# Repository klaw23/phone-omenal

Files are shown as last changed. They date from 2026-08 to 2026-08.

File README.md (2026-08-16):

# Phone-omenal 📞

**An open source telephone.** A box with an analog phone jack: plug in any
phone — a 1962 rotary, a Mickey Mouse phone, whatever the thrift store had —
and it calls other phones on your network through an open switchboard server
you (or anyone) can run. Everything is open: enclosure, electronics, firmware,
server.

The commercial inspiration is the Tin Can kids' landline; this is the
non-commercial, hackable, federated cousin.

## The build: ESP32 + a SLIC module + any old phone

**Start with [docs/esp32-build-guide.md](docs/esp32-build-guide.md).** It's the
whole project: complete parts and tools shopping list (~$120 all-in, no
soldering), a hardware crash course written for software engineers, and six
milestones — each one ends with something you can see or hear:

1. **Milestone 0** — stand up the Asterisk switchboard in Docker, call between
   two softphones (do this before any parts arrive)
2. **Hello world** — ESP-IDF toolchain, first flash
3. **Hook detection** — lift the handset, watch the serial log react
4. **Ring** — a real bell hammers because your for-loop said so
5. **Dial tone** — 350Hz + 440Hz through a real earpiece
6. **Digits** — decode rotary pulses (and touch-tones)
7. **The call** — dial 600 on a rotary phone, hear yourself echo back via SIP

## Repo layout

| Path | What |
|---|---|
| `docs/` | **The build guide — start here** · plus the provisioning & switchboard spec |
| `server/` | Asterisk switchboard + management web app: `docker compose up -d` and go |
| `firmware/` | Milestone example code matching the guide |
| `hardware/enclosure/` | Model 01 printed enclosure (OpenSCAD + STLs + 3D viewer) — fits the guide's electronics once they graduate from breadboard to perfboard |
| `future/` | Future work, tucked away: the Model 02 custom PCB and its smaller enclosure. Ignore until the breadboard build is making calls |

## Licenses

- Firmware & server configs: **MIT**
- Hardware (enclosure, PCB): **CERN-OHL-S v2**
- Documentation: **CC BY-SA 4.0**

## Standing on shoulders

[RetroPhone](https://github.com/ktownsend-personal/RetroPhone) proved the
ESP32+SLIC phone interface; [ESP32-SIP-Voice](https://github.com/GeorgeBregman/ESP32-SIP-Voice)
provides the SIP stack; [Asterisk](https://www.asterisk.org/) is the switch;
[PhreakNet](https://phreaknet.org/) and [NPSTN](https://npstn.us) showed hobbyist
phone networks are a thriving genre.

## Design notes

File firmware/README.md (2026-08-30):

# Firmware

Milestone example code referenced by the build guide
(`docs/esp32-build-guide.md`). Each file is the core of one milestone, written
for ESP-IDF v6.0.2 on the ESP32-A1S Audio Kit. They're deliberately small —
paste into an `idf.py create-project` skeleton as you reach each milestone,
rather than cloning something monolithic you didn't write yet.

| File | Milestone |
|---|---|
| `examples/01_hook.c` | Hook detection with debounce |
| `examples/02_ring.c` | Ring cadence generator |
| `examples/03_dialtone.c` | Dial/busy/ringback tone synthesis |
| `examples/04_digits.c` | Rotary pulse counting + MT8870 DTMF |
| `examples/05_provision.c` | WiFi with captive-portal fallback + LAN config page (spec §1) |
| `examples/06_ble_config.c` | Always-on BLE config GATT service (companion to 05) |
| `ble-config.html` | Web Bluetooth page that talks to 06 — open from disk in Chrome/Edge |

Milestone 5 (the actual SIP call) builds on
[ESP32-SIP-Voice](https://github.com/GeorgeBregman/ESP32-SIP-Voice) (MIT) —
the guide describes the grafting points. Once that integration exists as real
code, it lives here as `phone-omenal-fw/`.

GPIO assignments live at the top of each file; the guide's "AudioKit pin
caveat" explains why you might need to change them for your board revision.

`05_provision.c` and `06_ble_config.c` implement
`docs/provisioning-and-switchboard-spec.md`: captive portal only when WiFi is
failing, config page on the LAN IP (`http://phone-omenal.local`) once joined,
BLE reachable always, everything PIN-gated. Unlike 01–04 they are reference
code for a real subsystem rather than a bench exercise — wire them into the
Milestone 5 project alongside the SIP stack.

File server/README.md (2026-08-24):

# Switchboard server

Two pieces:

- **Asterisk** — the actual phone switch. Dialplan routes any 3–6 digit
  number starting 1–9, plus the service range (600 echo test, 601 playback).
  Endpoint definitions live in `asterisk/pjsip_devices.conf`.
- **Switchboard app** (`switchboard/`) — accounts, devices, and numbers, per
  the spec (`docs/provisioning-and-switchboard-spec.md`). Admins create users
  and approve number requests; users add devices and read their call logs; the
  boxes log in via its API to show status and the admin's contact email. It
  renders `pjsip_devices.conf` from its database and reloads Asterisk over AMI.

The app is optional for Milestone 0: `pjsip_devices.conf` ships with starter
extensions 101–103 so softphone testing works immediately.

## Docker (laptop/VPS/64-bit Pi)

On **Linux** (including a 64-bit Pi), host networking keeps SIP/RTP simple:

```bash
docker compose up -d
# web UI:
open http://localhost:8080     # log in: admin / changeme-admin (CHANGE IT)
# verify registrations:
docker exec -it phone-omenal-switchboard asterisk -rx "pjsip show contacts"
# watch RTP while debugging audio:
docker exec -it phone-omenal-switchboard asterisk -rx "rtp set debug on"
```

On **macOS/Windows** there is no host networking — Docker Desktop's "host" is
its Linux VM, so the containers come up healthy but `localhost:8080` refuses
the connection. Add the override, which publishes real ports and joins the app
to Asterisk's network namespace (so AMI stays on loopback, as on the Pi):

```bash
docker compose -f docker-compose.yml -f docker-compose.mac.yml up -d --build
```

It publishes 8080/tcp, 5060/udp, and the RTP range in `asterisk/rtp.conf`
(10000-10030 — deliberately narrow; every published UDP port costs a userland
proxy on Docker Desktop).

Before exposing anything beyond your LAN: set `ADMIN_PASSWORD`,
`SWITCHBOARD_SECRET`, and the AMI secret (`asterisk/manager.conf` +
`AMI_PASS` in `docker-compose.yml`) — the defaults are placeholders.

## Native install (better for 32-bit Pis like the Pi 2)

```bash
sudo apt update && sudo apt install asterisk python3-flask
sudo cp asterisk/*.conf /etc/asterisk/
sudo systemctl restart asterisk
sudo asterisk -rx "pjsip show endpoints"

# switchboard app (writes /etc/asterisk/pjsip_devices.conf, so run as a user
# that can — or point ASTERISK_CONF_DIR somewhere asterisk includes):
cd switchboard
ASTERISK_CONF_DIR=/etc/asterisk python3 app.py
```

## How number assignment flows

1. Admin creates a user (admin panel → Users).
2. User logs in, adds a device — a SIP password is generated.
3. User requests a number (a specific free one, or "next available").
4. Admin approves → the app writes the endpoint into `pjsip_devices.conf`,
   reloads Asterisk, and the user's device page shows the SIP credentials to
   type into the box's config page.

Numbers are 3–6 digits, never starting with 0 (`0…` is reserved for future
switchboard-to-switchboard dialing) and never in `6XX` (service range).

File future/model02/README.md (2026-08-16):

# Future work: Model 02 — the custom PCB

**Not the current project.** The current project is the ESP32 breadboard build
in `docs/esp32-build-guide.md`. This directory is a head start on what comes
*after* that works: collapsing the Audio Kit + perfboard + modules into a single
custom 80×54mm board, in a box half the size.

What's here, for when that day comes:

- `pcb/model02.kicad_pcb` — routed KiCad board (machine-routed rev A,
  DRC-clean electrically, **not yet reviewed by human eyes** — read
  `pcb/model02_board_design.md` §8 before spending money)
- `pcb/gerbers/` + `pcb/model02_bom.csv` + `pcb/model02_cpl_top.csv` — the
  JLCPCB upload set
- `pcb/model02_board_design.md` — the full engineering design doc
- `pcb/generator/` — the Python scripts that generate and route the board
- `model02.scad` / STLs / viewer — the matching smaller enclosure (91×65×28mm)

The right time to open this folder: the breadboard build makes calls reliably,
the firmware has settled, and you want ten of these instead of one.

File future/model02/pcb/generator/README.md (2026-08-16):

# Board generator

The Model 02 PCB is *generated*, not hand-drawn: `gen_board.py` places every
footprint and builds the full netlist with KiCad's pcbnew Python API, the
freerouting autorouter routes it (via Specctra DSN/SES: `import_ses.py`), and
`finish_board.py` stitches ground islands and runs DRC. To reproduce or modify:
edit the PARTS/NETS tables in gen_board.py and re-run the pipeline — the
design doc (../model02_board_design.md) explains every connection.

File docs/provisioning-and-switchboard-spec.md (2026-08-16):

# Phone-omenal — provisioning & switchboard spec

How a box gets configured, and how the switchboard manages people, devices,
and numbers. Firmware reference code: `firmware/examples/05_provision.c` and
`06_ble_config.c`. Server implementation: `server/switchboard/`.

## 1. Box configuration

The box stores five settings (in NVS flash): WiFi SSID, WiFi password,
switchboard address, SIP username (= its phone number), SIP password.
Plus a 4–8 digit **device PIN** (printed on a sticker inside the lid) that
gates every config surface.

Three ways in, one rule each:

| Surface | Available when | Why |
|---|---|---|
| **Captive portal** (box's own AP) | WiFi is failing: no stored credentials, or ~45s / 5 straight failed joins | First-time setup and "I typed the wrong password" recovery |
| **LAN config page** (`http://phone-omenal.local`) | Box is on WiFi | Everyday reconfiguration; the switchboard portal deep-links here per device |
| **BLE web config** (Web Bluetooth GATT) | Always advertising | Universal escape hatch — works even when WiFi is wedged. Chrome/Edge/Android only (no iOS Web Bluetooth); the portal covers everyone else |

The BLE page (`firmware/ble-config.html`) is pure client-side — the browser
talks GATT directly to the box, so no server hosts it. Web Bluetooth requires
a secure context (`https://`, `localhost`, or `file://`), which is why it is
NOT served by the plain-HTTP switchboard: open it from disk, or host it on
any HTTPS static host.

State machine:

```
            boot
             │
      creds stored? ──no──► AP MODE: SSID "Phone-omenal-XXXX",
             │yes           captive DNS, portal at 192.168.4.1
             ▼                  │ creds submitted
        JOIN WiFi ◄─────────────┘
        │        │
     joined    5 fails / 45s
        │        └──────────► AP MODE (portal shows last failure reason;
        ▼                     keeps retrying STA in the background — APSTA)
   CONNECTED: LAN page up, mDNS "phone-omenal",
   SIP registers, AP torn down
                                     BLE: advertising in every state
```

Rules:

- **Portal never coexists with calls** by construction: no WiFi → no SIP.
- The portal must display the last join failure ("wrong password for
  `MyWifi`", "no IP from DHCP") or users retry the same typo forever.
- **Auth**: every surface requires the device PIN before reading or writing
  anything. BLE additionally uses LE pairing. The LAN page is plain HTTP
  (TLS with a self-signed cert on an ESP32 only trains users to click through
  scare screens), so: LAN-only, PIN required, and **stored secrets are never
  echoed back** — the page shows `SSID: MyWifi ✓` and password fields stay
  blank.
- **Coexistence**: BLE advertises always, but GATT writes are deferred while
  a call is up (one 2.4GHz radio, time-sliced). Firmware uses NimBLE, not
  Bluedroid — RAM.
- After the box registers, it logs into the switchboard API with its SIP
  credentials and displays the **switchboard admin's email** on all three
  config surfaces ("problems? contact …").

## 2. Numbering plan

- A number is a dialable extension: digits only, 3–6 digits.
- **First digit is never 0.** The entire `0…` space is reserved as the
  inter-switchboard prefix for future federation (dial `0` + switchboard +
  number). The dialplan hard-reserves `_0.` so nothing can ever squat on it.
- **`6XX` is the service range** (600 echo test, 601 playback, future
  voicemail etc.) — not assignable to devices.
- Everything else (`100`–`599`, `700`–`999`, and longer) is assignable.
- One number ↔ one device. The number **is** the device's SIP username; a
  device without a number can't register (there'd be nothing to reach it at).

## 3. Switchboard roles

**Admin** (bootstrap account, has an email address — the one shown on boxes):

- create/disable user accounts
- create devices for any user, assign/change/release numbers directly
- approve or reject number requests
- see every device, registration status, and call log

**User** (created by an admin):

- add devices (each gets a generated SIP password, shown once)
- request a number for a device — a specific free one or "next available";
  assignment happens when an admin approves
- see their devices: number, registration status (from Asterisk), SIP
  credentials, and per-device call logs (from CDR)

## 4. Server architecture

```
Flask app (server/switchboard, SQLite) ──writes──► asterisk/pjsip_devices.conf
        │                                            (endpoint per number)
        ├──AMI :5038──► Asterisk  ("pjsip reload", "pjsip show contacts")
        └──reads──── /var/log/asterisk/cdr-csv/Master.csv  (call logs)
```

- The app owns `pjsip_devices.conf` (one `[number]` endpoint per assigned
  device, rendered from the DB) and reloads Asterisk over AMI after every
  change. `pjsip.conf` keeps the transport + templates and `#include`s it.
  The static dialplan needs no regeneration: `_[1-9]XX` (and longer
  patterns) already route any legal number.
- Registration status comes from parsing `pjsip show contacts` over AMI;
  call logs from the CDR CSV, filtered to rows where the device's number is
  caller or callee.
- Pi 2 friendly: Flask + SQLite + raw-socket AMI, no other dependencies.

## 5. HTTP API (used by the box and the BLE/portal pages)

| Endpoint | Auth | Returns |
|---|---|---|
| `POST /api/login` `{username, password}` | SIP creds (number + password) | `{token, number, owner, admin_email}` |
| `GET /api/me` | `Authorization: Bearer <token>` | same, minus token — the box polls this to show status + admin email |

Tokens are HMAC-signed, 24h expiry, no server-side session state.

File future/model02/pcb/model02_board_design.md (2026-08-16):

# Phone-omenal — Model 02 board design package

A single custom PCB that replaces the ESP32 Audio Kit + perfboard + breakout modules
from the Model 01 prototype. Design goal: **compactness** — one board, one USB-C cable,
one RJ11 jack, in a box barely bigger than a credit card footprint.

This document is everything except the CAD capture itself: exact parts, exact
connections, the floorplan, and the fab strategy. Capturing it in KiCad from these
tables is mechanical work (a focused weekend); every connection is specified below.
Board outline with hole and connector positions is provided as `model02_outline.dxf`
for direct import into KiCad's Edge.Cuts layer.

---

## 1. Architecture

```
                 ┌──────────────────────────────────────────────┐
  USB-C 5V ──►──┤ protection ─► 5V rail ────────► KS0835F SLIC ─┼──► RJ11 ──► phone
                 │     │                            ▲  ▲  │      │
                 │     └─► SY8089 buck ─► 3.3V      │  │  │audio │
                 │                          │       │  │  ▼      │
  USB-C D+/D- ──┼─► ESP32-S3-WROOM-1 ◄──────┘       │  │ ES8388  │
                 │      │     │  (native USB)       │  │ codec   │
                 │      │     └── GPIO: RM,F/R,PD ──┘  │  ▲      │
                 │      │         GPIO: SHK ◄──────────┘  │      │
                 │      ├── I2S + I2C ────────────────────┘      │
                 │      └── GPIO ◄── HT9170D DTMF ◄── audio tap  │
                 └──────────────────────────────────────────────┘
```

WiFi + SIP + G.711 run on the ESP32-S3. The ES8388 codec is the board's "sound card."
The KS0835F SLIC (still the proven off-the-shelf module, mounted flat on a right-angle
header) makes the analog phone line. The HT9170D decodes touch-tones in hardware —
the RetroPhone project's hard-won lesson is that software DTMF is unreliable, and this
chip is under a dollar. Rotary pulse dialing needs no hardware at all (counted on SHK).

Why the SLIC stays a module in rev A: a from-scratch SLIC (e.g. Si3210 ProSLIC) is a
serious analog/BOM undertaking with its own transformer-less ringing circuits. The
module is $8, proven in this exact role, and hand-solders in one minute. Integrating
a real SLIC chip is the natural Model 03 once the network exists.

## 2. Bill of materials

SMT parts are JLCPCB-assembly-friendly jellybeans; check live stock at order time
(all have drop-in equivalents). THT/manual parts marked ✋.

| Ref | Part (MPN) | Package | Role | ~$ |
|---|---|---|---|---|
| U1 | ESP32-S3-WROOM-1-N8R2 | module | MCU, WiFi, native USB | 3.50 |
| U2 | ES8388 | QFN-28 | stereo audio codec | 1.50 |
| U3 | HT9170D | SOIC-18 | DTMF receiver (MT8870-compatible) | 0.60 |
| U4 | SY8089A1AAC | SOT23-5 | 5V→3.3V buck, 2A | 0.30 |
| U5 | USBLC6-2SC6 | SOT23-6 | USB ESD protection | 0.25 |
| U6 | LM358 (DNP) | SOIC-8 | audio buffer stuffing option | 0.20 |
| M1 ✋ | KS0835F SLIC module | 11-pin SIL | FXS line interface | 8.00 |
| J1 ✋ | RJ11 6P4C jack, right-angle THT | — | phone line | 0.60 |
| J2 | USB-C receptacle 16-pin (e.g. TYPE-C-31-M-12) | SMT+shell | power + programming | 0.40 |
| J3 ✋ | 11-pin right-angle female header, 2.54mm | THT | SLIC mounts flat into this | 0.30 |
| X1 | 3.579545 MHz crystal | HC-49/SMD | HT9170D colorburst clock | 0.30 |
| Y1 | WS2812B-2020 | 2020 | status LED (front light pipe) | 0.15 |
| F1 | polyfuse 1A (MF-MSMF100) | 1812 | VBUS protection | 0.10 |
| D1 | SMBJ100CA bidirectional TVS | SMB | TIP/RING surge clamp (above ring voltage!) | 0.25 |
| L1 | 2.2µH, ≥2A | 0806/1212 | buck inductor | 0.10 |
| SW1, SW2 | tactile switch | SMT | EN, BOOT | 0.20 |
| — | R/C 0603 kit per section 4 | 0603 | ~30 passives | 1.00 |

Board: 2-layer, 1.6mm FR-4, HASL, **80 × 54 mm**, corners chamfered 6mm.
Five boards SMT-assembled at JLCPCB: roughly $60–90 + the five SLIC modules.
Solder M1/J1/J3 yourself (three parts, ten minutes).

## 3. ESP32-S3 pin map

| GPIO | Net | Dir | Notes |
|---|---|---|---|
| 19, 20 | USB D−, D+ | — | native USB (fixed pins), via U5 ESD |
| 1 / 2 | I2C SDA / SCL | I/O | ES8388 control (addr 0x10), 4.7k pullups |
| 4 | I2S MCLK | out | S3 routes MCLK on any pin via GPIO matrix |
| 5 / 6 | I2S BCLK / LRCLK | out | |
| 7 | I2S DOUT → codec DIN | out | ESP32 → phone audio |
| 8 | I2S DIN ← codec DOUT | in | phone → ESP32 audio |
| 10 | SLIC SHK | in | hook status + pulse dialing, **via divider** (§4.3) |
| 11 | SLIC RM | out | ring mode enable |
| 12 | SLIC F/R | out | toggle at 20 Hz while RM high = ring |
| 13 | SLIC PD | out | SLIC power-down |
| 14, 15, 17, 18 | HT9170 Q1–Q4 | in | decoded DTMF digit |
| 21 | HT9170 DV | in | data-valid, use as interrupt |
| 38 | WS2812 DIN | out | status LED |
| 0 | BOOT switch | in | strapping pin, rear pinhole access |

Strapping pins 3, 45, 46 left unconnected/default. All chosen GPIOs avoid
flash/PSRAM-reserved pins on the WROOM-1 module.

## 4. Subsystem circuits

### 4.1 Power
- USB-C VBUS → F1 polyfuse → **5V rail** (powers SLIC directly — ring generation
  is strongest at 5V). CC1/CC2 each pulled to GND with 5.1k (advertises 5V/up-to-3A sink).
- 5V → U4 SY8089 buck (L1 1µH, 22µF in, 2×22µF out) → **3.3V rail** for ESP32-S3,
  ES8388, HT9170D. WiFi TX bursts hit ~500mA; the 2A buck loafs. (Pad-compatible
  AMS1117 fallback footprint optional but the buck runs cool and is the same price.)
- Bulk: 100µF electrolytic or 2×22µF ceramic on the 5V rail near the SLIC — ring
  bursts draw current spikes.

### 4.2 Audio path (the part that earns the board its keep)
ES8388 is stereo; the phone line is mono — use LOUT1/RIN1, leaving a spare channel.

- **To the phone:** ES8388 LOUT1 → 100Ω series → 4.7µF film/X7R coupling cap →
  SLIC **VR** (audio input). Provision R-divider pads (DNP 0Ω/open by default) to
  trim level in rev A bring-up.
- **From the phone:** SLIC **VX** → 4.7µF coupling → 10k series → ES8388 **RIN1**
  (line input, not mic input — VX is line level). PGA in the codec handles fine trim.
- **DTMF tap:** VX also feeds HT9170D via the datasheet single-ended network:
  0.1µF into IN−, 100k input R, 100k feedback R IN−→GC, IN+ to VREF. X1 crystal
  + 2×18pF across OSC1/OSC2.
- **Stuffing option:** U6 LM358 buffer footprints sit in both audio legs, bypassed
  by 0Ω links by default. If levels or impedances disappoint during bring-up
  (RetroPhone needed an op-amp here), populate U6 and its gain network instead of
  respinning. This is the cheapest insurance on the board.
- **Ring-bleed filter:** RetroPhone reports the 20Hz ring bleeding into audio.
  Provision a simple RC high-pass (DNP) at RIN1 (e.g. 300Hz corner: 10k + 47nF) —
  telephone audio is 300–3400Hz anyway, and firmware mutes the codec during ring
  cadence as the first line of defense.

### 4.3 SLIC interface (M1 on J3, lying flat)
KS0835F pinout: 1-2 RING/TIP, 3 F/R, 4 RM, 5 SHK, 6 VR, 7 VX, 8 NC, 9 GND,
10 +5V, 11 PD.

- Supply pin 10 from the 5V rail with 100µF nearby.
- **SHK is 5V logic → divider 10k/15k to GPIO10** (3.0V high). RM/F/R/PD are
  driven at 3.3V, which clears TTL V_IH at 5V supply — direct connection.
- TIP/RING → J1 RJ11 center pair, with D1 (SMBJ100CA) across the pair. The TVS
  must stand off the ~±60–90V ring pulses, hence 100V. This is a desk device with
  a 2m handset cord, not a building wiring run — heavier telecom protection
  (TISP surge protectors, line fuses) is a Model 03 concern.
- Keep-out: route TIP/RING and the SLIC's line side away from codec inputs;
  20 mil clearance minimum on the ring-voltage nets.

### 4.4 Misc
- EN: 10k pullup + 1µF to GND + SW1 to GND. BOOT: SW2 on GPIO0, reachable through
  a 2mm pinhole in the rear wall (firmware updates are OTA after first flash;
  the pinhole is the break-glass path).
- WS2812B-2020 at the front edge behind a 3mm light pipe: registration status,
  ring flash, "line claimed" colors — the box's only face.

## 5. Floorplan (80 × 54, origin front-left, dims in mm)

```
 rear  ┌──────────────────────────────────────────────┐
       │ [ESP32-S3 ▓antenna→edge]   [USB-C @ x=40]  ○ │   ○ = M2.5 holes at
       │   x=7..25, keep-out under    [BOOT pinhole]  │   (10,10)(70,10)
       │   antenna: no copper       [buck U4 + L1]    │   (10,44)(70,44)
       │                                              │
       │        [KS0835F lying flat on J3]            │   corners chamfered 6mm
       │         50 × 20 zone, x≈20..71               │   (clears the enclosure's
       │                                              │    corner screw posts)
       │ [ES8388+passives]     [HT9170D + X1]         │
       │                                              │
       │  [RJ11 J1 @ x=25]   [LED Y1 @ x=60]          │
 front └──────────────────────────────────────────────┘
```

- ESP32-S3 antenna overhangs/abuts the rear edge with full copper keep-out beneath.
- Buck loop (U4-L1-caps) tight, far corner from the codec; WS2812 data line routed
  away from audio nets.
- J1 and J2 protrude through the enclosure walls; Y1 sits 1mm behind the front wall
  light-pipe hole.
- Ground pour both layers, stitched; single reference, star only the SLIC's
  noisy 5V leg.

## 6. Fab & assembly plan

1. JLCPCB 2-layer, HASL, any color (it lives in a box). Economic SMT assembly,
   top side only — every SMT part above is from their parts-library ecosystem;
   substitute equivalents for anything out of stock at order time.
2. Hand-solder J1, J3 (and the USB-C shell tabs if you chose the THT-shell variant).
3. Push M1 (SLIC module) into J3. It lies flat over the board, max height ~13mm.
4. First power-up **without** M1: verify 5V, 3.3V, USB enumeration, flash firmware.
5. Insert M1, run bring-up in the same ladder as the breadboard: SHK detect →
   ring test → dial tone → DTMF/pulse digits → SIP call.

Order 5 boards and expect to want a rev B — that is normal and cheap (~$2/bare
board on re-order). Rev A's DNP stuffing options (LM358 path, dividers, RC filter)
exist precisely so most surprises are jumper changes, not respins.

## 7. What the compactness buys

| | Model 01 (modules) | Model 02 (custom board) |
|---|---|---|
| Boards inside | AudioKit + perfboard + 3 modules | one |
| Tallest part | SLIC standing, 20.3mm | SLIC flat, ~13mm |
| Enclosure | 145 × 101 × 39 mm | **91 × 65 × 28 mm** (≈½ the volume) |
| Cables inside | 15+ jumpers | zero |
| Cost @ qty 5 | ~$35/unit in modules | ~$25/unit assembled + module |
| Programming | USB-UART on AudioKit | native USB-C, OTA after first flash |

Enclosure files: `model02.scad`, `model02_base.stl`, `model02_lid.stl` — same
open-source enclosure language (rotary-dial vents, engraved nameplate), rebuilt
around this board's exact connector positions.

## 8. Rev A as-built (KiCad files)

The generated, routed board (`model02.kicad_pcb`) supersedes a few §2/§5 details:

- **USB-C moved to x=55** on the rear edge. The stock KiCad ESP32-S3-WROOM-1
  footprint embeds Espressif's antenna keep-out, which covers the rear-LEFT
  region — the connector now sits clear of it (better RF, too).
- **Mounting holes** ended up at (33,12), (70,10), (10,37), (70,44) after
  clearing the module, codec, and connector courtyards. The enclosure
  (`model02.scad`) and `model02_outline.dxf` are updated to match.
- ES8388 is **QFN-28** (its only package); buck uses 2.2µH with a 100k/22k
  FB divider (0.6V reference → 3.3V).
- Routing: freerouting autorouter + scripted cleanup; **DRC: 0 electrical
  violations, 0 unconnected items**. Remaining DRC entries are cosmetic
  (silkscreen label overlaps, library-sync notices).
- Honest caveat: this is a machine-routed rev A. It is electrically correct
  per the netlist and passes DRC, but no human has eyeballed the analog
  routing. Treat the first 5 boards as the bring-up batch they are.

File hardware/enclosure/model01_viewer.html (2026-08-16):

# Phone-omenal — Model 01

closedexplodedinterior

145 × 101 × 39 mm · drag to orbit, scroll to zoom · CERN-OHL-S

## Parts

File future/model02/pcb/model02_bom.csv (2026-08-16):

Designator | Value | Footprint | MPN / note
U1 | ESP32-S3-WROOM-1-N8R2 | ESP32-S3-WROOM-1 | ESP32-S3-WROOM-1-N8R2
U2 | ES8388 | QFN-28-1EP_5x5mm_P0.5mm_EP3.35x3.35mm | ES8388
U3 | HT9170D | SOIC-18W_7.5x11.6mm_P1.27mm | HT9170D
U4 | SY8089AAAC | SOT-23-5 | SY8089AAAC
U5 | USBLC6-2SC6 | SOT-23-6 | USBLC6-2SC6
J1 | RJ11-6P4C | RJ14_Connfly_DS1133-S4_Horizontal | RJ11 6P4C DS1133-S4
J2 | USB-C 16pin | USB_C_Receptacle_HRO_TYPE-C-31-M-12 | TYPE-C-31-M-12
J3 | KS0835F socket | PinSocket_1x11_P2.54mm_Horizontal | 2.54mm 1x11 R/A socket
F1 | 1A polyfuse | Fuse_1812_4532Metric | MF-MSMF100
D1 | SMBJ100CA | D_SMB | SMBJ100CA
L1 | 2.2uH | L_1210_3225Metric | generic 2.2uH
X1 | 3.579545MHz | Crystal_SMD_HC49-SD | 3.579545MHz HC49-SMD
Y1 | WS2812B-2020 | LED_WS2812B-2020_PLCC4_2.0x2.0mm | WS2812B-2020
SW1 | EN | SW_SPST_TL3342 | generic EN
SW2 | BOOT | SW_SPST_TL3342 | generic BOOT
R1 | 5.1k | R_0603_1608Metric | generic 5.1k
R2 | 5.1k | R_0603_1608Metric | generic 5.1k
R4 | 100R | R_0603_1608Metric | generic 100R
R6 | 10k | R_0603_1608Metric | generic 10k
R7 | 100k | R_0603_1608Metric | generic 100k
R8 | 100k | R_0603_1608Metric | generic 100k
R10 | 10k | R_0603_1608Metric | generic 10k
R11 | 15k | R_0603_1608Metric | generic 15k
R12 | 300k | R_0603_1608Metric | generic 300k
R13 | 330R | R_0603_1608Metric | generic 330R
R14 | 10k | R_0603_1608Metric | generic 10k
R15 | 100k | R_0603_1608Metric | generic 100k
R16 | 22k | R_0603_1608Metric | generic 22k
RP1 | 4.7k | R_0603_1608Metric | generic 4.7k
RP2 | 4.7k | R_0603_1608Metric | generic 4.7k
C1 | 22uF | C_0805_2012Metric | generic 22uF
C2 | 22uF | C_0805_2012Metric | generic 22uF
C3 | 22uF | C_0805_2012Metric | generic 22uF
C4 | 22uF | C_0805_2012Metric | generic 22uF
C5 | 4.7uF | C_0805_2012Metric | generic 4.7uF
C6 | 4.7uF | C_0805_2012Metric | generic 4.7uF
C7 | 100nF | C_0603_1608Metric | generic 100nF
C8 | 100nF | C_0603_1608Metric | generic 100nF
C9 | 1uF | C_0603_1608Metric | generic 1uF
C10 | 100uF | CP_Elec_6.3x5.8 | generic 100uF
C12 | 100nF | C_0603_1608Metric | generic 100nF
C13 | 100nF | C_0603_1608Metric | generic 100nF
C14 | 100nF | C_0603_1608Metric | generic 100nF
C15 | 100nF | C_0603_1608Metric | generic 100nF
C16 | 100nF | C_0603_1608Metric | generic 100nF
C17 | 10uF | C_0805_2012Metric | generic 10uF
C18 | 10uF | C_0805_2012Metric | generic 10uF
C19 | 100nF | C_0603_1608Metric | generic 100nF
C20 | 18pF | C_0603_1608Metric | generic 18pF
C21 | 18pF | C_0603_1608Metric | generic 18pF

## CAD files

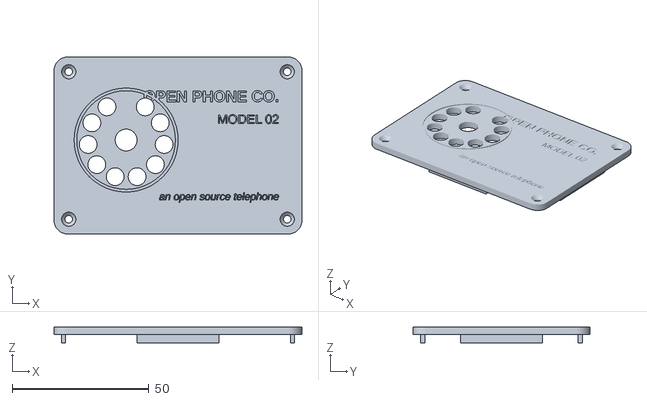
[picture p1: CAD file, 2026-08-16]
future/model02/model02_lid.stl
90.8 x 64.8 x 5.80

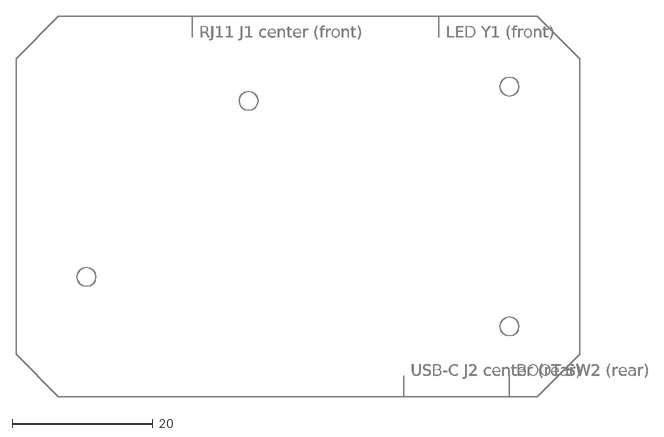
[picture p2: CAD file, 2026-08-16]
future/model02/pcb/model02_outline.dxf
RJ11 J1 center (front)
USB-C J2 center (rear)
LED Y1 (front)
BOOT SW2 (rear)

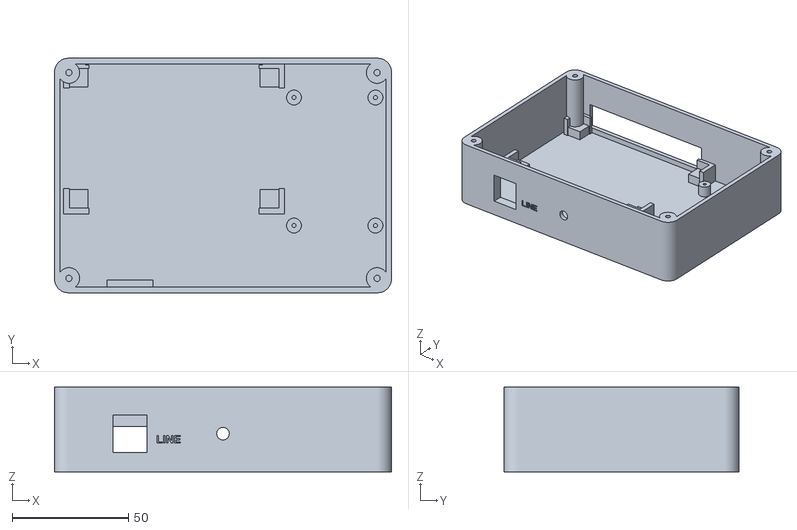
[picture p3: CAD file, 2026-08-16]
hardware/enclosure/model01_base.stl
144.8 x 100.8 x 36.4

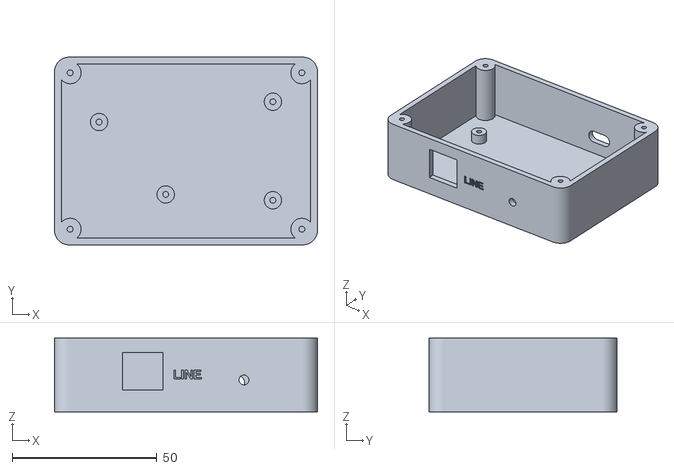
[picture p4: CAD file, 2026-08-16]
future/model02/model02_base.stl
90.8 x 64.8 x 25.4

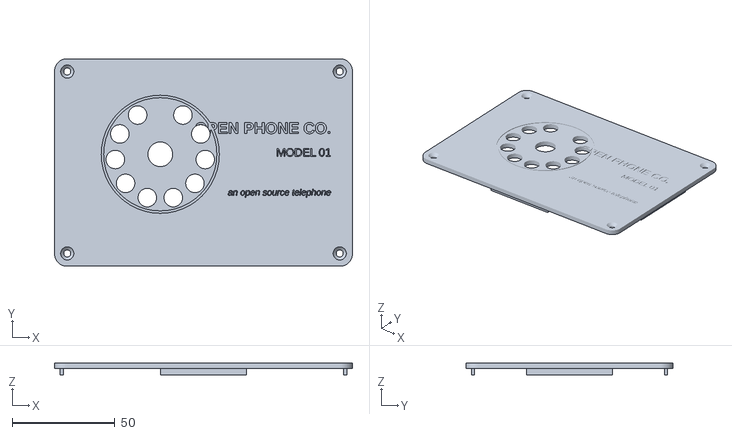
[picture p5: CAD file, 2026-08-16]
hardware/enclosure/model01_lid.stl
144.8 x 100.8 x 6.00

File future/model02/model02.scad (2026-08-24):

// ============================================================
//  PHONE-OMENAL — "Model 02" enclosure
//  Built around the custom 80x54mm PCB (see model02_board_design.md):
//  on-board RJ11, USB-C, WS2812 light pipe, SLIC module lying flat.
//  License: CERN-OHL-S / CC-BY-SA
//
//  part = "base" | "lid" | "components" | "display" | "exploded" | "interior"
// ============================================================

part = "display";

/* ---------- parameters (mm) ---------- */
wall = 2.4; floor_th = 2.4; lid_th = 2.8; corner_r = 5;

ix = 86; iy = 60; iz = 23;          // interior

// PCB: 80x54, chamfer C6, at (3,3); top of PCB sits at floor+4+1.6
pcb_x = 3;  pcb_y = 3;  pcb_w = 80; pcb_d = 54; pcb_ch = 6;
standoff_h = 4; pcb_top = floor_th + standoff_h + 1.6;
// mounting holes at board (10,10)(70,10)(10,44)(70,44) -> interior:
so_pts = [[36,15],[73,13],[13,40],[73,47]];  // matches PCB holes (33,12)(70,10)(10,37)(70,44)

// front-face features (board coords -> interior x = board x + 3)
rj_cx = 28;  rj_w = 14;  rj_z0 = floor_th+5.1; rj_z1 = floor_th+18.1; // RJ11 opening
led_cx = 63; led_d = 3.4; led_z = floor_th+8.6;                      // light pipe
// rear-face features
usb_cx = 58; usb_w = 10.5; usb_z0 = floor_th+5.1; usb_z1 = floor_th+10.1;
boot_cx = 73; boot_d = 2.2; boot_z = floor_th+7.6;                   // BOOT pinhole

// lid screws M2.5 into corner posts
post_r = 3.8; pin = 3.0; pilot = 2.05; shaft = 2.7; head = 5.2;
post_pts = [[pin,pin],[ix-pin,pin],[pin,iy-pin],[ix-pin,iy-pin]];

// rotary-dial vents
dial_cx = 24; dial_cy = 32; dial_r = 14; dial_hole_d = 6.5; dial_n = 10;

label_text = "PHONE-OMENAL";
label_sub  = "MODEL 02";

ox = ix + 2*wall; oy = iy + 2*wall; base_h = floor_th + iz;
$fn = 48;

/* ---------- helpers ---------- */
module rrect(w, d, r) { hull() for (x=[r,w-r], y=[r,d-r]) translate([x,y]) circle(r=r); }
module rbox(w, d, h, r) { linear_extrude(h) rrect(w, d, r); }
module chamfered_pcb() {
  polygon([[pcb_ch,0],[pcb_w-pcb_ch,0],[pcb_w,pcb_ch],[pcb_w,pcb_d-pcb_ch],
           [pcb_w-pcb_ch,pcb_d],[pcb_ch,pcb_d],[0,pcb_d-pcb_ch],[0,pcb_ch]]);
}

/* ============================================================ BASE */
module base() {
  difference() {
    union() {
      difference() {
        translate([-wall,-wall,0]) rbox(ox, oy, base_h, corner_r);
        translate([0,0,floor_th]) rbox(ix, iy, iz+1, corner_r-wall);
      }
      // corner posts (lid screws, M2.5)
      for (p=post_pts) translate([p[0],p[1],floor_th]) cylinder(r=post_r, h=iz);
      // PCB standoffs (M2.5)
      for (p=so_pts) translate([p[0],p[1],floor_th]) cylinder(r=3.0, h=standoff_h);
    }
    // post pilot holes
    for (p=post_pts) translate([p[0],p[1],floor_th+iz-10]) cylinder(d=pilot, h=10.1);
    // standoff pilot holes (into floor for thread depth)
    for (p=so_pts) translate([p[0],p[1],floor_th-1.4+standoff_h-4]) cylinder(d=pilot, h=5.5);
    // RJ11 opening (front)
    translate([rj_cx-rj_w/2, -wall-0.5, rj_z0]) cube([rj_w, wall+2, rj_z1-rj_z0]);
    // LED light-pipe hole (front)
    translate([led_cx, 0.5, led_z]) rotate([90,0,0]) cylinder(d=led_d, h=wall+1.5);
    // USB-C slot (rear), rounded ends
    hull() for (sx=[-1,1])
      translate([usb_cx+sx*(usb_w/2-(usb_z1-usb_z0)/2), iy+wall+0.5, (usb_z0+usb_z1)/2])
        rotate([90,0,0]) cylinder(d=usb_z1-usb_z0, h=wall+1.5);
    // BOOT pinhole (rear)
    translate([boot_cx, iy+wall+0.5, boot_z]) rotate([90,0,0]) cylinder(d=boot_d, h=wall+1.5);
    // engravings
    translate([rj_cx+rj_w/2+3.5, -wall+0.5, floor_th+9]) rotate([90,0,0])
      linear_extrude(1) text("LINE", size=3.2, font="Liberation Sans:style=Bold");
    translate([usb_cx-usb_w/2-3.5, iy+wall-0.5, floor_th+6]) rotate([90,0,180])
      linear_extrude(1) text("PWR", size=3.2, halign="left", font="Liberation Sans:style=Bold");
  }
}

/* ============================================================ LID */
module lid() {
  difference() {
    union() {
      translate([-wall,-wall,0]) rbox(ox, oy, lid_th, corner_r);
      // alignment tabs at edge midspans
      tab_l = 30; tab_t = 1.6; tab_h = 3.0; inset = 0.3;
      translate([ix/2-tab_l/2, inset, -tab_h])          cube([tab_l, tab_t, tab_h]);
      translate([ix/2-tab_l/2, iy-inset-tab_t, -tab_h]) cube([tab_l, tab_t, tab_h]);
      translate([inset, iy/2-tab_l/2, -tab_h])          cube([tab_t, tab_l, tab_h]);
      translate([ix-inset-tab_t, iy/2-tab_l/2, -tab_h]) cube([tab_t, tab_l, tab_h]);
    }
    // countersunk M2.5 screw holes
    for (p=post_pts) {
      translate([p[0],p[1],-0.1]) cylinder(d=shaft, h=lid_th+0.2);
      translate([p[0],p[1],lid_th-1.5]) cylinder(d1=shaft, d2=head, h=1.51);
    }
    // rotary-dial vents
    for (i=[0:dial_n-1]) {
      a = 90 + 30 + i*(300/(dial_n-1));
      translate([dial_cx+dial_r*cos(a), dial_cy+dial_r*sin(a), -0.1])
        cylinder(d=dial_hole_d, h=lid_th+0.2);
    }
    translate([dial_cx, dial_cy, -0.1]) cylinder(d=8, h=lid_th+0.2);
    // engraved dial ring
    translate([dial_cx, dial_cy, lid_th-0.6]) difference() {
      cylinder(r=dial_r+dial_hole_d/2+1.8, h=0.7);
      translate([0,0,-0.1]) cylinder(r=dial_r+dial_hole_d/2+0.8, h=0.9);
    }
    // engraved labels
    translate([80, 46, lid_th-0.6]) linear_extrude(0.7)
      text(label_text, size=4.2, halign="right", font="Liberation Sans:style=Bold");
    translate([80, 38, lid_th-0.6]) linear_extrude(0.7)
      text(label_sub, size=3.4, halign="right", font="Liberation Sans");
    translate([80, 10, lid_th-0.6]) linear_extrude(0.7)
      text("an open source telephone", size=2.8, halign="right", font="Liberation Sans:style=Italic");
  }
}

/* ============================================================ COMPONENTS */
module components() {
  // PCB
  color([0.13,0.42,0.25]) translate([pcb_x,pcb_y,floor_th+standoff_h])
    linear_extrude(1.6) chamfered_pcb();
  z0 = pcb_top;
  // ESP32-S3 module (rear-left, antenna at rear edge)
  color([0.75,0.75,0.78]) translate([10,31.5,z0]) cube([18,25.5,3.2]);
  color([0.2,0.2,0.22])   translate([12,53,z0+0.4]) cube([14,3.5,1]);   // antenna zone
  // KS0835F lying flat on right-angle header
  color([0.1,0.1,0.12]) translate([30,20,z0+1.5]) cube([50.2,20.3,13]);
  // ES8388 codec + HT9170D
  color([0.2,0.2,0.2]) translate([15,14,z0]) cube([7,7,1.2]);
  color([0.2,0.2,0.2]) translate([64,13,z0]) cube([11,7,2]);
  // RJ11 jack (front, snout through wall)
  color([0.95,0.95,0.92]) translate([rj_cx-6.5,-1,floor_th+5.6]) cube([13,16,12]);
  // USB-C stub (rear)
  color([0.75,0.75,0.78]) translate([usb_cx-4.5,iy-7,z0]) cube([9,8.5,3.2]);
  // WS2812 LED
  color([0.9,0.85,0.4]) translate([led_cx-1,3.5,z0]) cube([2,2,1]);
}

/* ============================================================ ASSEMBLIES */
module shell_color() { color([0.93,0.88,0.78]) children(); }

if (part == "base") base();
else if (part == "lid") lid();
else if (part == "components") components();
else if (part == "display") { shell_color() base(); shell_color() translate([0,0,base_h]) lid(); }
else if (part == "interior") { shell_color() base(); components(); }
else if (part == "exploded") {
  shell_color() base(); components();
  shell_color() translate([0,0,base_h+40]) lid();
}

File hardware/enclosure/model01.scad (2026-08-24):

// ============================================================
//  PHONE-OMENAL — "Model 01" enclosure
//  Open-source enclosure for an ESP32 SIP phone box:
//    - Ai-Thinker ESP32-A1S Audio Kit (~90 x 60 mm)  [measure yours!]
//    - 60x40 perfboard carrying KS0835F SLIC + MT8870 + level shifter
//    - RJ11 keystone jack on the front
//  License: CERN-OHL-S / CC-BY-SA — do whatever, share alike.
//
//  part = "base" | "lid" | "components" | "display" | "exploded" | "interior"
// ============================================================

part = "display";

/* ---------- main parameters (mm) ---------- */
wall      = 2.4;      // wall thickness
floor_th  = 2.4;      // floor thickness
lid_th    = 2.8;      // lid plate thickness
corner_r  = 6;        // outer corner radius

ix = 140;             // interior width  (x)
iy = 96;              // interior depth  (y)
iz = 34;              // interior height (z, above floor)

// ESP32 Audio Kit bay (board + tolerance)
audio_w = 90;  audio_d = 60;  audio_standoff = 5;

// perfboard (common 60x40, mounting holes ~55x35, M2)
perf_w = 40; perf_d = 60; perf_hole_dx = 35; perf_hole_dy = 55;
perf_cx = 118; perf_cy = 54; perf_post_h = 6;

// RJ11 keystone cutout (standard keystone: 14.5 x 16.0)
key_w = 14.7; key_h = 16.1; key_cx = 30; key_z = 6;

// status LED hole (5mm LED)
led_d = 5.4; led_cx = 70; led_z = 14;

// rear connector slot for AudioKit edge (USB x2 + jacks)
slot_w = 76; slot_cx = 49; slot_z0 = 3; slot_z1 = 17;

// lid screws (M3 self-tap into posts)
post_r = 4.6; screw_pilot = 2.7; screw_head = 6.4; screw_shaft = 3.4;

// lid vent: rotary-dial pattern
dial_cx = 49; dial_cy = 52; dial_r = 22; dial_hole_d = 9; dial_n = 10;

label_text = "PHONE-OMENAL";
label_sub  = "MODEL 01";

/* ---------- derived ---------- */
ox = ix + 2*wall;         // outer footprint
oy = iy + 2*wall;
base_h = floor_th + iz;   // base outer height
$fn = 48;
// screw post centers, sunk 0.8mm into the walls so the union is clean
pin = post_r - 0.8;
post_pts = [[pin,pin],[ix-pin,pin],[pin,iy-pin],[ix-pin,iy-pin]];

/* ---------- helpers ---------- */
module rrect(w, d, r) {
  hull() for (x=[r, w-r], y=[r, d-r]) translate([x,y]) circle(r=r);
}
module rbox(w, d, h, r) { linear_extrude(h) rrect(w, d, r); }

/* ============================================================
   BASE
   ============================================================ */
module base() {
  difference() {
    union() {
      // outer shell
      difference() {
        translate([-wall,-wall,0]) rbox(ox, oy, base_h, corner_r);
        translate([0,0,floor_th]) rbox(ix, iy, iz+1, corner_r-wall);
      }
      // corner screw posts
      for (p=post_pts)
        translate([p[0],p[1],floor_th]) cylinder(r=post_r, h=iz);
      // AudioKit corner grips: ledge + lip at each board corner
      audiokit_grips();
      // perfboard posts (M2)
      for (dx=[-1,1], dy=[-1,1])
        translate([perf_cx+dx*perf_hole_dx/2, perf_cy+dy*perf_hole_dy/2, floor_th])
          difference() {
            cylinder(r=3.2, h=perf_post_h);
            translate([0,0,perf_post_h-5]) cylinder(r=0.9, h=5.1);
          }
      // keystone tunnel reinforcement on front wall
      translate([key_cx-key_w/2-2.5, -0.5, floor_th])
        cube([key_w+5, 3.5, key_z+key_h+2.5]);
    }
    // screw pilot holes
    for (p=post_pts)
      translate([p[0],p[1],floor_th+iz-12]) cylinder(r=screw_pilot/2, h=12.1);
    // keystone cutout (front wall, y = -wall..3+)
    translate([key_cx-key_w/2, -wall-0.5, floor_th+key_z])
      cube([key_w, wall+4.5, key_h]);
    // LED hole
    translate([led_cx, 0.5, floor_th+led_z])
      rotate([90,0,0]) cylinder(d=led_d, h=wall+1.5);
    // rear connector slot
    translate([slot_cx-slot_w/2, iy-0.5, floor_th+slot_z0])
      cube([slot_w, wall+1, slot_z1-slot_z0]);
    // engrave "LINE" beside the jack
    translate([key_cx+key_w/2+4, -wall+0.5, floor_th+key_z+4]) rotate([90,0,0])
      linear_extrude(1) text("LINE", size=3.4, halign="left", font="Liberation Sans:style=Bold");
  }
}

// one grip drawn for a (+x,+y) corner at origin, mirrored into place
module grip_pp() {
  cube([8, 8, audio_standoff]);                          // ledge the board rests on
  translate([-2.5,-2.5,0]) cube([11, 2.5, audio_standoff+5]);  // outer lip, L-shaped
  translate([-2.5,-2.5,0]) cube([2.5, 11, audio_standoff+5]);  // (overlapping corner)
}
module audiokit_grips() {
  bx = 4; by = iy - 2 - audio_d;   // board front-left corner
  translate([bx,          by,          floor_th]) scale([ 1, 1,1]) grip_pp();
  translate([bx+audio_w,  by,          floor_th]) scale([-1, 1,1]) grip_pp();
  translate([bx,          by+audio_d,  floor_th]) scale([ 1,-1,1]) grip_pp();
  translate([bx+audio_w,  by+audio_d,  floor_th]) scale([-1,-1,1]) grip_pp();
}

/* ============================================================
   LID
   ============================================================ */
module lid() {
  difference() {
    union() {
      translate([-wall,-wall,0]) rbox(ox, oy, lid_th, corner_r);
      // alignment tabs (skirt segments along edge midspans, clear of posts)
      tab_l = 42; tab_t = 1.6; tab_h = 3.2; inset = 0.3;
      for (s = [ [ix/2-tab_l/2, inset, tab_l, tab_t],
                 [ix/2-tab_l/2, iy-inset-tab_t, tab_l, tab_t] ])
        translate([s[0], s[1], -tab_h]) cube([s[2], s[3], tab_h]);
      for (s = [ [inset, iy/2-tab_l/2, tab_t, tab_l],
                 [ix-inset-tab_t, iy/2-tab_l/2, tab_t, tab_l] ])
        translate([s[0], s[1], -tab_h]) cube([s[2], s[3], tab_h]);
    }
    // countersunk screw holes over posts
    for (p=post_pts) {
      translate([p[0],p[1],-0.1]) cylinder(d=screw_shaft, h=lid_th+0.2);
      translate([p[0],p[1],lid_th-1.7]) cylinder(d1=screw_shaft, d2=screw_head, h=1.71);
    }
    // rotary-dial vent holes
    for (i=[0:dial_n-1]) {
      a = 90 + 30 + i*(300/(dial_n-1));   // arc like a real dial (gap at bottom)
      translate([dial_cx + dial_r*cos(a), dial_cy + dial_r*sin(a), -0.1])
        cylinder(d=dial_hole_d, h=lid_th+0.2);
    }
    // center hole of the "dial"
    translate([dial_cx, dial_cy, -0.1]) cylinder(d=12, h=lid_th+0.2);
    // engraved dial ring
    translate([dial_cx, dial_cy, lid_th-0.6]) difference() {
      cylinder(r=dial_r+dial_hole_d/2+2.2, h=0.7);
      translate([0,0,-0.1]) cylinder(r=dial_r+dial_hole_d/2+1.0, h=0.9);
    }
    // engraved labels (right-aligned block, clear of the dial)
    translate([132, 62, lid_th-0.6]) linear_extrude(0.7)
      text(label_text, size=5.6, halign="right", font="Liberation Sans:style=Bold");
    translate([132, 51, lid_th-0.6]) linear_extrude(0.7)
      text(label_sub, size=4.0, halign="right", font="Liberation Sans");
    translate([132, 32, lid_th-0.6]) linear_extrude(0.7)
      text("an open source telephone", size=3.2, halign="right", font="Liberation Sans:style=Italic");
  }
}

/* ============================================================
   COMPONENT MOCKUPS (for visualization only)
   ============================================================ */
module components() {
  bx = 4; by = iy - 2 - audio_d;
  // ESP32 Audio Kit
  color([0.13,0.4,0.2]) translate([bx,by,floor_th+audio_standoff]) cube([audio_w,audio_d,1.6]);
  color([0.25,0.25,0.28]) translate([bx+30,by+38,floor_th+audio_standoff+1.6]) cube([28,17,3.2]); // ESP32-A1S module
  color([0.75,0.75,0.78]) { // USB stubs through rear slot
    translate([bx+18,by+audio_d-3,floor_th+audio_standoff+1.6]) cube([8,7,3]);
    translate([bx+38,by+audio_d-3,floor_th+audio_standoff+1.6]) cube([8,7,3]);
  }
  color([0.1,0.1,0.1]) translate([bx+62,by+audio_d-5,floor_th+audio_standoff+1.6]) cube([7,9,5]); // headphone jack
  // perfboard
  color([0.82,0.7,0.45]) translate([perf_cx-perf_w/2, perf_cy-perf_d/2, floor_th+perf_post_h]) cube([perf_w,perf_d,1.6]);
  // KS0835F SLIC (SIL stick standing up)
  color([0.1,0.1,0.12]) translate([perf_cx-6.5, perf_cy-25, floor_th+perf_post_h+1.6]) cube([13,50.2,20.3]);
  // MT8870 module
  color([0.15,0.3,0.6]) translate([perf_cx-11, perf_cy+28-52, floor_th+perf_post_h+1.6+0]) ;
  color([0.15,0.3,0.6]) translate([perf_cx+8, perf_cy-21, floor_th+perf_post_h+1.6]) cube([9,42,10]);
  // keystone jack body
  color([0.95,0.95,0.92]) translate([key_cx-8, 0, floor_th+key_z-2]) cube([16,22,key_h+4]);
}

/* ============================================================
   ASSEMBLIES
   ============================================================ */
module shell_color() { color([0.93,0.88,0.78]) children(); }  // warm cream PLA

if (part == "base")        base();
else if (part == "lid")    lid();
else if (part == "components") components();
else if (part == "display") {
  shell_color() base();
  shell_color() translate([0,0,base_h]) lid();
}
else if (part == "interior") {
  shell_color() base();
  components();
}
else if (part == "exploded") {
  shell_color() base();
  components();
  shell_color() translate([0,0,base_h+45]) lid();
}

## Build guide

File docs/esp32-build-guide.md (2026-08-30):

# Building the Phone-omenal — ESP32 breadboard guide

This guide takes you from zero hardware experience to a rotary phone on your desk
making SIP calls through an ESP32. It's written for a software engineer: every
hardware concept is introduced the first time it's needed, every milestone ends
with something observable, and nothing asks you to trust a step you can't verify.

The shape of the project, in software terms: you're building a driver (the ESP32
firmware that speaks "telephone" out one side and SIP out the other), against a
server (Asterisk, the open-source phone switch), with hardware bring-up as a
series of integration tests that happen to involve a physical bell.

Total budget: **about $120** including tools you'll keep forever. Time: four or
five evenings, comfortably spread out.

---

## 1. Shopping list

### Electronics (~$60)

| Part | ~Price | Where | Notes |
|---|---|---|---|
| **ESP32-A1S Audio Kit** (Ai-Thinker) | $15–20 | Amazon / AliExpress | The dev board. An ESP32 with an ES8388 audio codec already wired up — this is what makes two-way call audio tractable. Any revision works; note yours (silkscreen says V2.2 usually). |
| **KS0835F SLIC module** | $8–10 | eBay / AliExpress | The magic part: generates the voltage, ring signal, and audio interface a real telephone expects. Search "KS0835F SLIC". Buy two — they're the one part with shipping lag, and a spare is cheap insurance. |
| **MT8870 DTMF decoder module** | $4 | Amazon / eBay | Decodes touch-tone beeps to 4-bit digits. **Skip this if you'll only use rotary phones** — pulse dialing needs no extra hardware. |
| **A telephone** | $5–15 | Thrift store / eBay | Any corded analog phone. Get two eventually: a touch-tone one for easy debugging, a rotary one for joy. Avoid cordless phones and anything with a wall-wart. |
| **RJ11 screw-terminal breakout** (or sacrifice a phone cord) | $5 | Amazon "RJ11 breakout" | Gives you screw terminals for the phone line so nothing needs soldering. |
| **Solderless breadboard, 830 points** | $6 | anywhere | The prototyping surface. |
| **Breadboard power supply module** (MB102 or clone) | $4 | Amazon "MB102 breadboard power supply" | **Needed** — the AudioKit's headers are 3V3 only, and the SLIC wants 5V. Straddles the board and feeds the rails; runs off USB. Its ~700mA ceiling is fine until ringing (§6). |
| **Jumper wire kit** (M-M and M-F) | $6 | anywhere | M-F ones connect breadboard to the AudioKit's pin headers. |
| **3.5mm aux cable** (to cut in half) | $3 | anywhere | Carries audio between the AudioKit's jacks and the SLIC. |
| Resistor/capacitor kit **or** just: 2× 10k, 1× 15k resistors (10k + 4.7k in series substitutes for the 15k), 2× 4.7µF and 2× 100nF capacitors | $8 kit | Amazon "resistor capacitor assortment" | A kit is worth it; you'll use it forever. Capacitors: ceramic or film, ≥16V rating. |

### Tools (~$45, one-time)

| Tool | ~Price | Why |
|---|---|---|
| **Multimeter** | $15 | Your `printf` for electricity. Any cheap auto-ranging one (e.g. AstroAI-class) is fine. |
| **USB data cable** matching the AudioKit (usually micro-USB) | $5 | Must be a *data* cable — many charging cables have no data wires and produce maddening "no port found" symptoms. |
| **Wire stripper** | $10 | For the aux cable and phone cord. Scissors work in a pinch; strippers preserve sanity. |
| **Small screwdriver set** | $8 | Screw terminals, phone shells. |
| Optional: **alligator clip jumpers** | $6 | Clip onto phone-line wires without any termination. |

No soldering iron is required for this phase. (You'll want one eventually; that's
a later problem.)

---

## 2. Hardware crash course (15 minutes of concepts)

**GPIO.** A general-purpose pin the chip can read (input) or drive (output) as a
digital 1 (3.3V) or 0 (0V). In firmware you configure direction, then read/write.
Think of each pin as a one-bit syscall.

**3.3V vs 5V logic.** The ESP32 speaks 3.3V. A 5V signal into an ESP32 pin can
damage it over time. When a 5V device sends us a signal, we drop it through a
**voltage divider**: two resistors in series to ground, signal tapped between
them. 10k on top, 15k on the bottom turns 5V into 3V — safely readable. (Ratio =
bottom/(top+bottom) = 0.6.) Signals *from* the ESP32 *to* a 5V device are usually
fine as-is: 3.3V still counts as "high" for TTL-style inputs.

**Debouncing.** Mechanical contacts (hook switches, buttons) don't switch
cleanly — they chatter for a few milliseconds. You debounce in software:
"believe a new state only after it's been stable for 15ms." A rotary dial is
just a switch that bounces *on purpose*, ten times a second.

**Breadboard anatomy.** The two long rails down each side are power rails (mark
one red = 3.3V or 5V, one blue = GND). The middle rows connect 5 holes
horizontally per row, split by the center trench. Chips straddle the trench.

**Multimeter basics.** Set to DC volts, black probe on GND, red probe on the
thing. You'll use it for exactly three questions: "is this rail 3.3/5V?",
"is this pin high or low?", "are these two points connected?" (continuity mode,
it beeps).

**What the SLIC does.** A telephone expects the wall to feed it ~48V of loop
current, detect when the handset lifts (which closes the loop), superimpose
audio on the same two wires, and slam 60–90V of 20Hz AC onto them to ring the
bell. The KS0835F module does all of that from a 5V supply and exposes a clean
3-wire digital interface plus audio in/out:

| SLIC pin | Name | Meaning |
|---|---|---|
| 1, 2 | RING, TIP | The two phone-line wires (polarity doesn't matter for normal phones) |
| 3 | F/R | Toggle at 20Hz (while RM high) to ring the bell |
| 4 | RM | Ring mode enable |
| 5 | SHK | **Output**: high = handset lifted. Also pulses during rotary dialing |
| 6 | VR | Audio **into** the phone (earpiece) |
| 7 | VX | Audio **out of** the phone (mouthpiece) |
| 8 | NC | not connected |
| 9 | GND | ground |
| 10 | +VDC | 3.3–5V supply |
| 11 | PD | power-down control (tie low/leave managed by GPIO) |

**⚡ The one safety note.** During ringing, TIP and RING carry 60–90V AC pulses.
That's the same thing every phone line in history has carried — startling, not
dangerous, but it will get your attention. Rules: don't touch the phone-line
terminals while the ring test is running, and rewire only with USB unplugged.
Everything else on this project is 5V or less.

---

## 3. Milestone 0 — the server (no hardware needed)

Do this first, before any parts arrive. When the hardware later misbehaves,
you'll know the server side is solid — halving every future debugging search.

You need a machine for **Asterisk**, the open-source phone switch: a $5 VPS, a
Raspberry Pi, or your laptop (fine for the desk phase; the box needs to reach it
over the LAN).

**Path A — Docker** (laptop, VPS, Pi 3+/64-bit): with the `server/` directory
from this repo:

```bash
cd server
docker compose up -d
```

**Path B — native install** (best for older Pis like the Pi 2, whose 32-bit ARM
makes Docker images scarce — and a Pi 2 handles this job with ease; G.711 calls
relay with near-zero CPU):

```bash
sudo apt update && sudo apt install asterisk
sudo cp server/asterisk/pjsip.conf server/asterisk/extensions.conf /etc/asterisk/
sudo systemctl restart asterisk
sudo asterisk -rx "pjsip show endpoints"    # should list 101, 102, 103
```

Shelf-duty tips for a Pi server: a proper 2A power supply (undervoltage is the
classic source of mystery flakiness), a decent SD card, and a static IP or DHCP
reservation so the phones' registration target never moves.

Either path starts Asterisk with three extensions defined: `101`, `102`, `103`
(phones) and `600` (an echo test — it answers and plays your own voice back).
Docker also starts the **switchboard web app** on `:8080` — accounts, number
assignment, and per-device call logs (see
`provisioning-and-switchboard-spec.md`). It's optional at this milestone; the
starter extensions work without it.

Now install **Linphone** (free softphone) on your laptop and phone. Register two
accounts against your server: username `101` password `changeme-101` and `102`/
`changeme-102`, server = the machine's IP, transport UDP. Call `102` from `101`.
Call `600` and hear yourself.

When that works, you have a phone network. Everything after this is "build an
unusual SIP client."

> **Concept check — how SIP calls work:** registration means the client tells
> the server "extension 101 is at this IP." A call is an `INVITE` through the
> server, then audio flows as RTP packets (G.711 codec = 8kHz, 64kbps, the
> literal sound of a landline). Asterisk relays both signaling and audio, which
> is why NAT at each house doesn't break things.

---

## 4. Milestone 0.5 — toolchain and hello world

### 4a. Prerequisites the extension will *not* install for you

The ESP-IDF extension (and the newer ESP-IDF Installation Manager) downloads the
compiler, flasher, and Python environment itself — but it expects a handful of
system tools to already exist, and it refuses to go any further if one is
missing. On a fresh Mac the usual complaint is **`dfu-util`**.

Install them first:

```bash
# macOS
brew install dfu-util ccache cmake ninja
xcode-select --install          # only if `git` is missing

# Debian / Ubuntu / Raspberry Pi OS
sudo apt install git wget flex bison gperf python3 python3-venv python3-pip \
     cmake ninja-build ccache libffi-dev libssl-dev dfu-util libusb-1.0-0
```

On Windows, use Espressif's **offline installer** instead — it bundles all of
this and sidesteps the whole problem.

Check them before you open the editor. Every line must say a path:

```bash
for t in dfu-util ccache cmake ninja python3 git; do
  printf '%-10s %s\n' "$t" "$(command -v $t || echo MISSING)"
done
```

### 4b. macOS: if it *still* says missing after you installed it

Usually installing the tool is the whole fix — reopen VS Code and the check
passes. If a prerequisite you know is installed is still reported missing, the
cause is almost always that the extension can't see Homebrew.

Apps launched from the Dock inherit only a bare `/usr/bin:/bin:/usr/sbin:/sbin`
from `launchd`, and Homebrew lives in `/opt/homebrew/bin` (Apple Silicon) or
`/usr/local/bin` (Intel). VS Code normally works around this: on macOS it spawns
your login shell at startup and adopts its environment, so extensions do get
your real `PATH`. But that resolution can fail — an unusual shell, a `.zshrc`
that exits early under non-interactive use, or a slow profile that times out.

Check whether your login shell exposes the tool at all:

```bash
/bin/zsh -lic 'command -v dfu-util'
```

If that prints a path but the extension still disagrees, launch VS Code from a
terminal so it inherits the environment directly rather than deriving it:

1. `Cmd+Shift+P` → **Shell Command: Install 'code' command in PATH**
2. Quit VS Code with `Cmd+Q` — closing the window leaves the old process and
   its environment alive.
3. `code /path/to/phone-omenal`

Note this is per-launch, not a one-time repair: a process takes its environment
at start, so a Dock launch tomorrow gets the old behaviour again. If you need it
permanently, fix the environment rather than the launch method — make sure the
Homebrew `shellenv` line is somewhere your login shell reads unconditionally,
or set a `PATH` for GUI apps via a LaunchAgent.

### 4c. Python: beware version managers

ESP-IDF builds its own virtualenv, but it needs a real interpreter to build it
*from*. If your `python3` is a **pyenv/asdf shim**, the extension may fail to
resolve it — shims depend on shell initialisation that a GUI process never ran.

```bash
command -v python3        # a path under ~/.pyenv/shims is the warning sign
pyenv which python3       # the real binary it points at
```

If setup fails on Python, point the extension at the real binary rather than the
shim: setting `idf.pythonInstallPath`, or the custom-path field in Express
install. Prefer a **3.9–3.12** interpreter unless your IDF version's release
notes say otherwise — IDF trails new Python releases, so a bleeding-edge
Homebrew Python is a worse choice than an older managed one.

### 4d. Install ESP-IDF and flash hello world

**1. Install ESP-IDF** via the VS Code extension ("ESP-IDF" by Espressif →
"Express install"). Take **v6.0.2**, the current stable release. This gives you
the compiler, flasher, and serial monitor in one.

The installer can keep several versions side by side, and **ESP-IDF: Select
Current ESP-IDF Version** switches between them — useful if a third-party
component you pull in later has not caught up with v6 yet.

**2. Plug the AudioKit into the right socket.** The board has *two* micro-USB
ports. Use the one labelled **UART** — it's wired to the onboard CP2102
USB-to-serial bridge and carries 5V as well as data, so a single cable both
powers and flashes the board. The other port is power-only; its data lines go
nowhere, so the board lights up but no serial device ever appears. (That second
port earns its keep at Milestone 2: ringing draws far more current than a laptop
USB port likes, and you can feed it 5V/2A there while keeping the laptop on
UART.)

**3. Confirm the serial port appeared.** It's a device file, not a notification:

```bash
ls /dev/cu.*           # macOS — run before and after plugging in
ls /dev/ttyUSB*        # Linux
```

Look for a new `/dev/cu.usbserial-*` or `/dev/cu.SLAB_USBtoUART` (Windows:
a new `COMx` in Device Manager). On macOS use **`cu.*`, not `tty.*`** — the
`tty.*` node blocks waiting for a carrier-detect signal the board never
asserts, which hangs esptool in a way that looks like dead hardware.

Nothing there? This one command tells you which of two very different problems
you have:

```bash
system_profiler SPUSBDataType | grep -iE 'CP210|Silicon Labs|CH34|FTDI'
```

- **Prints something, but no `/dev/cu.*`** — the chip enumerated and the driver
  didn't bind. Uncommon on current macOS, which ships a CP210x driver; this is
  when you go get Silicon Labs' VCP driver.
- **Prints nothing** — the board isn't reaching USB at all. In order of
  likelihood: wrong socket (see step 2), a charge-only USB cable, dead board.

**4. Create the project.** In extension v2.x:

```
Cmd/Ctrl+Shift+P → ESP-IDF: New Project
```

Name it, then pick `hello_world` from **get-started** in the template chooser.
Set the target to **`esp32`** — the AudioKit is a classic ESP32, not an S3.
Then Build, Flash, Monitor.

> Older tutorials tell you to run **ESP-IDF: Show Examples Projects**. That
> command no longer exists; examples now live inside the New Project wizard.
> `ESP-IDF: Create New Empty Project` is a different thing — a bare skeleton,
> which defeats the point of a known-good smoke test. If you want a guided
> version matched to your installed extension, run `Welcome: Open Walkthrough`
> → ESP-IDF; "Creating an Example Project" is step 3.

If the wizard stops with **"no framework selected to load examples"**, the
extension does not know which ESP-IDF install to draw them from:

1. `Developer: Reload Window` — settings written during setup are often not
   live until the window reloads.
2. `ESP-IDF: Select Current ESP-IDF Version` → pick your install.
3. In the wizard's template step, check the framework dropdown actually reads
   **ESP-IDF**.

Note that extension v2.x stores this in a single setting, `idf.currentSetup`,
replacing the older `idf.espIdfPath` / `idf.toolsPath` pair that most
tutorials still reference. Setup writes it to the **workspace** it was run in,
so opening a different folder can leave you with no framework selected again —
copy it into your User settings if you want it everywhere.

When `Hello world!` scrolls past at 115200 baud, your toolchain is proven.
IDF's build/flash/monitor loop is your inner dev loop from here on — treat
`idf.py flash monitor` like `npm run dev`.

---

## 5. Milestone 1 — hook detection (first wires)

**Goal:** serial log prints `OFF HOOK` / `ON HOOK` as you lift the handset.

### 5a. Breadboard basics

Skip if you've used one. If you haven't, these three rules cover everything in
this guide.

**The long rails** down each edge run the length of the board. Marked `+` (red)
and `−` (blue). Every hole in one rail is the same electrical point, so it
doesn't matter which you use. Two things to check on an unfamiliar board: the
left and right rails are **not** joined to each other unless you jumper them,
and some boards **split each rail in the middle** — look for a gap in the
printed line. A continuity check between the two ends of a rail settles both in
seconds.

**The short rows** in the middle connect **5 holes horizontally**, and stop dead
at the centre trench. Row 12 on the left of the trench and row 12 on the right
are unrelated.

**A row is a node.** This is the idea the wiring diagrams assume. You join
components by putting their legs in the same row — there's no such thing as
attaching a wire to the middle of a resistor. When a diagram says "tap", that
means *a row you pick*, not a part you own.

**Jumper wires** are just wires with connectors, and every `→` below means "run
one between these points". M-M (pin/pin) goes hole-to-hole; M-F (pin/socket)
connects a breadboard hole to a male pin on a board. Check which your AudioKit
needs — revisions ship with pins or sockets.

Use red wire for anything reaching the red rail and black for the blue rail.
Not electrically required, but it turns a fifteen-connection debugging session
from ten minutes into ten seconds.

### 5b. Powering the SLIC — the AudioKit has no 5V pin

**The ESP32-A1S Audio Kit does not break out 5V on its pin headers.** Both power
pins are 3V3, and there are two of each because boards duplicate power pins for
convenience — all GND pins are the same net, as are all 3V3 pins. The SLIC needs
5V on +VDC, so it needs its own supply.

Don't substitute 3V3. Hook detection gets flaky and the bell won't ring properly
at Milestone 2.

The easy answer is a **breadboard power module** (the MB102 and its clones,
a few dollars) that straddles the board and feeds the rails directly:

- **Input:** USB *or* the DC barrel jack, not both. **Use USB** — it's already
  5V, and Milestone 1 draws almost nothing. The barrel jack wants 7–9V because
  its linear regulator can only step *down* and needs headroom; it exists for
  when you need more current than a USB port gives.
- **Jumpers:** one per rail, selecting `3.3V` / `OFF` / `5V` for *that rail*.
  They are not input selectors, despite sitting next to the input connectors.
  Set the rail you're building against to **5V**.
- **Pins:** typically two pairs at each end, doubled per rail row for
  mechanical stability, energising both sides' rails. Seat all of them, evenly
  and fully — a partial seat gives an intermittent connection that works until
  you nudge the board.

> **Check polarity before anything else is connected.** These modules can seat
> one row off, putting `+` on the blue rail. Power on, multimeter on DC volts,
> black on blue rail and red on red rail: **~5.0V** is right, **−5.0V** means
> reversed and would destroy the SLIC, **3.3V** means the jumper is wrong.

**The one rule that makes two supplies safe:** the AudioKit's GND and the 5V
supply's ground must be connected. Two sources with separate grounds means the
SLIC's signals have no shared reference and every reading is meaningless. Step 2
below does this.

### 5c. Wiring

Wire it all with the module's power switch **off**.

1. **AudioKit `GND` → blue rail.** Either GND pin, any hole. This is the common
   ground — it ties the AudioKit to the module's `−`, already on that rail.
2. **SLIC pin 10 (+VDC) → red rail**
3. **SLIC pin 9 (GND) → blue rail**
4. **SLIC pin 5 (SHK) → row 10**
5. **10k: one leg row 10, other leg row 15**
6. **15k: one leg row 15, other leg → blue rail**
7. **Row 15 → AudioKit `GPIO19`**
8. **SLIC pin 11 (PD) → AudioKit `GPIO23`**
9. **SLIC pins 1 & 2 → RJ11 breakout centre pair**

Steps 5–7 are the voltage divider from the crash course. SHK swings to 5V
because we feed the SLIC 5V; the divider scales that to 5V × 15/(10+15) = **3V**,
safe for the ESP32's 3.3V input. **Row 15 is the tap** — three legs share it:
the 10k, the 15k, and the jumper to the ESP32. That sharing *is* the connection.
Row numbers are arbitrary.

**No 15k?** Series resistances add, so 10k + 4.7k = 14.7k works — the tap lands
at 2.98V instead of 3V, well within the tolerance of the resistors themselves.
Wire it as 10k (row 10 → row 15), 4.7k (row 15 → row 20), 10k (row 20 → blue
rail). **Row 20 must contain only those two resistor legs** — that private
junction is what "in series" means physically. Anything else in it shorts out
part of the divider.

Drive PD low in firmware (powered up).

**On step 9:** RJ11 is the telephone connector; a breakout is a socket with
screw terminals so you needn't solder. A phone line uses only **two** wires, by
convention the middle two, coloured **red and green** — outer positions are a
second line, unused. Both are needed because a phone line is a **loop**:
current flows out one wire, through the handset, back the other. The two are
called **tip** and **ring**, after the parts of an operator's plug. Polarity
doesn't matter for a standard analog phone. Note there's no connection to your
breadboard ground here — the line floats, which is normal.

> Once powered these two wires sit at ~48V DC, rising to 60–90V AC while
> ringing. Not lethal, but a ring burst is a memorable belt. Rewire with the
> supply off, and don't hold the terminals during Milestone 2.

### 5d. Verify before you trust the firmware

Multimeter on **continuity** — the `•)))` sound-wave symbol, usually sharing a
dial position with the diode symbol `▶|`; press SELECT to toggle. Black probe in
`COM`, red in `VΩmA` (not the 10A jack). **Touch the probes together first: it
must beep.** Otherwise every test below lies to you.

Power **off**:

- **A. Red rail ↔ blue rail — must NOT beep.** A beep is a short across your
  supply. Find it before switching on.
- **B. AudioKit GND ↔ blue rail — should beep.** Confirms step 1.

Power **on**, DC volts, black probe on the blue rail throughout:

- **C. Red rail → ~5.0V** (see the polarity warning in 5b)
- **D. Row 15 → ~0V on-hook, ~3V off-hook**

**Check D is the whole milestone.** If that number moves correctly, the hardware
is right and anything remaining is firmware.

> **AudioKit pin caveat — read before wiring.** This board shares pins liberally
> between the headers, SD slot, and onboard keys, and revisions differ. On
> V2.2, **GPIO 5, 13, 18, 19 and 23 are wired to the six onboard KEY buttons**
> (19 is KEY3, 23 is KEY4), GPIO21 is amplifier control and GPIO22 drives an
> LED — which is every pin this guide reaches for. The onboard circuitry can
> fight your divider. The signature is check D reading a clean swing while the
> firmware never sees a change. If that happens, pull your revision's schematic
> (one page, findable by "ESP32 Audio Kit V2.2 schematic"), pick a header pin
> with nothing else attached, and change the `#define` — every pin number in the
> example code is one. Also note silkscreen shortens `GPIO19` to `IO19`; if
> yours prints something like `IO19 / KEY3`, the board is telling you the pin is
> already taken. Leave the SD slot empty and all DIP switches OFF regardless.

### Firmware — the paste-into-hello-world loop

Each milestone reuses the hello-world project from §4: **select all in
`main/hello_world_main.c`, replace with the milestone's code, rebuild, flash.**
One project, one file, and the diff between milestones is exactly the code you
just read. The snippets below are complete — includes and all — and match the
files in `firmware/examples/`, which are the canonical copies.

Two things about the build system before the first paste:

**How the build knows what to compile:** `main/CMakeLists.txt` lists it
explicitly —

```cmake
idf_component_register(SRCS "hello_world_main.c"
                       PRIV_REQUIRES spi_flash
                       INCLUDE_DIRS "")
```

`SRCS` names the source files; that's why replacing the *contents* of
`hello_world_main.c` needs no build changes, while adding a second `.c` file
would mean listing it here (and two files each defining `app_main` won't link).

**One edit you must make (once):** the hello-world template sets
`MINIMAL_BUILD ON` in the root `CMakeLists.txt`, so only components `main`
declares get built. The milestone code uses GPIO and the high-resolution
timer, which aren't in the default list — pasting without this edit fails with
`fatal error: driver/gpio.h: No such file or directory`. Change the
`PRIV_REQUIRES` line to:

```cmake
                       PRIV_REQUIRES spi_flash esp_driver_gpio esp_timer
```

That covers milestones 1–4. When a later paste hits the same error with a
different header, the error message itself names the component to append —
ESP-IDF prints "add X to PRIV_REQUIRES" at the bottom of the failure.

`firmware/examples/01_hook.c`:

```c
#include <stdio.h>
#include "freertos/FreeRTOS.h"
#include "freertos/task.h"
#include "driver/gpio.h"
#include "esp_timer.h"

#define PIN_SHK  19
#define PIN_PD   23

void app_main(void) {
    gpio_config_t in = { .pin_bit_mask = 1ULL << PIN_SHK, .mode = GPIO_MODE_INPUT };
    gpio_config(&in);
    gpio_config_t out = { .pin_bit_mask = 1ULL << PIN_PD, .mode = GPIO_MODE_OUTPUT };
    gpio_config(&out);
    gpio_set_level(PIN_PD, 0);              // SLIC awake

    bool stable = false, raw, last_raw = false;
    int64_t change_us = 0;
    while (true) {
        raw = gpio_get_level(PIN_SHK);
        if (raw != last_raw) { change_us = esp_timer_get_time(); last_raw = raw; }
        if (raw != stable && esp_timer_get_time() - change_us > 15000) {  // 15ms debounce
            stable = raw;
            printf(stable ? "OFF HOOK\n" : "ON HOOK\n");
        }
        vTaskDelay(pdMS_TO_TICKS(2));
    }
}
```

Lift the handset: `OFF HOOK`. That's your first hardware/software integration
test passing. (If it's inverted, your SLIC reports the opposite sense — just
flip the comparison. If it never changes, multimeter the divider tap: ~3V
off-hook, ~0V on-hook.)

## 6. Milestone 2 — make it ring

**Goal:** a physical bell rings, in proper US cadence, from your code.

Add two wires: SLIC pin 4 (RM) → GPIO22, SLIC pin 3 (F/R) → GPIO21.

(full file: `firmware/examples/02_ring.c` — paste it whole, this shows the shape)

```c
#include "freertos/FreeRTOS.h"
#include "freertos/task.h"
#include "driver/gpio.h"

#define PIN_RM 22
#define PIN_FR 21

// Ring: RM high, toggle F/R at 20Hz. US cadence: 2s ringing, 4s silence.
void ring_task(void *arg) {
    while (true) {
        gpio_set_level(PIN_RM, 1);
        for (int i = 0; i < 80; i++) {                 // 80 half-cycles = 2s at 20Hz
            gpio_set_level(PIN_FR, i & 1);
            vTaskDelay(pdMS_TO_TICKS(25));
            if (off_hook()) goto answered;              // stop instantly on pickup
        }
        gpio_set_level(PIN_RM, 0);
        for (int i = 0; i < 400; i++) {                // 4s silence, still watching hook
            vTaskDelay(pdMS_TO_TICKS(10));
            if (off_hook()) goto answered;
        }
    }
answered:
    gpio_set_level(PIN_RM, 0);
    vTaskDelete(NULL);
}
```

Trigger it from a serial command or just on boot. A rotary phone's bell hammer
physically slamming because your `for` loop said so is the moment this project
hooks people. If the ring is feeble, check the 5V supply and the 100µF-worth of
capacitance near the SLIC (add a cap from the kit across 5V/GND).

## 7. Milestone 3 — dial tone

**Goal:** lift the handset, hear a real dial tone.

Audio path wiring, using the cut aux cable:
- AudioKit **headphone out** → one channel's wire → **4.7µF capacitor** → SLIC
  pin 6 (VR). The capacitor is "AC coupling" — it passes audio, blocks DC.
- SLIC pin 7 (VX) → 4.7µF capacitor → the other half of the aux cable → AudioKit
  **line/aux in**. (Which jack or pad is line-in varies by AudioKit revision —
  the schematic page from Milestone 1's caveat shows yours. Some revisions route
  only onboard mics; then solder pads or use the second jack.)
- All grounds common (cable shields to the blue rail).

For the codec you don't write a driver: clone
[ESP32-SIP-Voice](https://github.com/GeorgeBregman/ESP32-SIP-Voice) and reuse
its ES8388 init (I2C config + I2S stream at 8kHz). With the codec streaming,
dial tone is just math — North American dial tone is 350Hz + 440Hz summed:

(full file: `firmware/examples/03_dialtone.c` — paste it whole, this shows the shape)

```c
#include <math.h>
#include <stdint.h>
#include <stdbool.h>

// fill I2S buffer with dial tone, 8kHz mono, 16-bit
static float ph1, ph2;
void fill_dialtone(int16_t *buf, int n) {
    for (int i = 0; i < n; i++) {
        float s = sinf(ph1) * 0.25f + sinf(ph2) * 0.25f;
        ph1 += 2*M_PI*350/8000; ph2 += 2*M_PI*440/8000;
        buf[i] = (int16_t)(s * 32767);
    }
}
```

Gate it on the hook state from Milestone 1: off-hook → stream dial tone; digit
dialed → stop. Expect to fiddle with codec output volume vs what sounds right in
the earpiece — this level-matching is the project's fussiest hour. Log
everything; adjust one variable at a time.

## 8. Milestone 4 — digits

**Rotary (no extra hardware):** a rotary dial interrupts the loop N times for
digit N, at 10 pulses/sec. So on SHK you'll see, mid-off-hook, short breaks:
~60ms low, ~40ms high. Classify: break of 20–90ms = pulse; quiet gap >300ms =
digit boundary; 10 pulses = "0".

(full file: `firmware/examples/04_digits.c` — paste it whole, this shows the shape)

```c
#include <stdio.h>
#include "freertos/FreeRTOS.h"
#include "freertos/queue.h"
#include "driver/gpio.h"
#include "esp_timer.h"

// inside the debounced hook handler:
// on->off edge while off-hook: possible pulse start (t0 = now)
// off->on edge: if 20ms < now-t0 < 90ms -> pulse_count++
// timer: 300ms with no pulses and pulse_count>0 -> digit = pulse_count%10; emit
```

Watch the serial log while you dial 4: `pulse pulse pulse pulse digit=4`.
Deeply satisfying.

**Touch-tone (MT8870 module):** power the module from **3.3V** (the CM8870 chip
in these clones runs 2.5–5.5V — at 3.3V its outputs are ESP32-safe with no
dividers; if yours proves flaky at 3.3V, run it at 5V and divide all five
outputs like SHK). Audio input of the module connects across VX/GND through its
onboard network. Wire `StD` (data valid) → GPIO18, `Q1..Q4` → GPIO5, 13, 14, 15.
On StD's rising edge, read Q1–Q4 as a nibble: 1–9 are literal, 10 = `0`,
11 = `*`, 12 = `#`.

```c
static void IRAM_ATTR dtmf_isr(void *arg) {
    int d = gpio_get_level(PIN_Q1) | gpio_get_level(PIN_Q2)<<1
          | gpio_get_level(PIN_Q3)<<2 | gpio_get_level(PIN_Q4)<<3;
    // queue it; 10 means '0'
}
```

## 9. Milestone 5 — the phone call

**Goal:** dial `600` on the rotary phone, hear yourself echo back from Asterisk.
Then dial `102` and your laptop rings.

ESP32-SIP-Voice already implements registration, INVITE/BYE, and G.711 RTP with
ES8388 audio — on its own it's a working softphone with buttons. Your work is
replacing its button UI with the telephone state machine you've now built piece
by piece:

```
        IDLE ──off-hook──► DIALTONE ──first digit──► COLLECTING
          ▲                                             │ 3 digits (or 4s timeout)
          │ on-hook (anywhere)                          ▼
        [end call, stop tones]                       CALLING ──SIP 200──► IN_CALL
                                                        │                    ▲
        RINGING ◄──incoming INVITE── IDLE               └──486 busy──► BUSY_TONE
           │ off-hook ──────────────────────────────────────────────────► IN_CALL
```

Concretely: configure the repo's WiFi + SIP settings (server IP, user `101`,
password) so it registers — verify with `docker exec -it <asterisk> asterisk
-rx "pjsip show contacts"`. Then graft: collected digits → its call-start
function; its incoming-call callback → your `ring_task`; hook events → its
answer/hangup functions; in-call, its audio pipeline already moves codec ↔ RTP,
which is now phone ↔ RTP because of your Milestone-3 wiring. Busy tone
(480+620Hz, 0.5s on/off) and ring-back are your dial-tone generator with
different constants — landline nostalgia is mostly a table of sine frequencies.

There will be an evening of "registers but no audio" or "audio one way" —
that's telephony's hazing ritual. It's almost always: wrong RTP address
(Asterisk `direct_media` must stay off), codec mismatch (force G.711/`ulaw` both
ends), or a muted codec channel. `asterisk -rx "rtp set debug on"` shows you
packets in real time, and Wireshark speaks SIP natively if you want the whole
conversation.

## 10. Milestone 6 — box it

Print `hardware/enclosure/model01_*.stl` (the design in this repo sized for
exactly these modules: AudioKit bay, 60×40 perfboard posts for SLIC + MT8870
when you graduate from breadboard, keystone RJ11 opening). PETG or PLA, lid
face-down, supports only under the rear slot. Assembly: four M3×12 into the
posts, RJ11 keystone snaps into the front. The rotary-dial vent pattern on the
lid is load-bearing for morale.

(Much later, when the breadboard build is boring because it just works:
`future/model02/` holds a designed-but-unbuilt custom PCB that collapses all of
this into one small board. It's future work — ignore it for now.)

---

## 11. Troubleshooting

| Symptom | Usual culprit |
|---|---|
| No serial port | Wrong micro-USB socket (use the **UART** one, §4d), then charge-only USB cable, then CP210x driver. `system_profiler SPUSBDataType \| grep CP210` tells you which |
| Extension says a prerequisite is missing (`dfu-util`, `cmake`, `ninja`) | Install it (§4a) and reopen VS Code. If it's installed and *still* reported missing on macOS, the extension can't see Homebrew — §4b |
| "No framework selected to load examples" | Reload the window, then `ESP-IDF: Select Current ESP-IDF Version`. The setting is per-workspace (§4d) |
| ESP-IDF setup fails on Python | `python3` is probably a pyenv/asdf shim; point the extension at the real binary, Python 3.9–3.12 (§4c) |
| Boot loops / flash fails | Hold BOOT during flash; check DIP switches off; try lower baud |
| Nothing works, or readings make no sense with two supplies | AudioKit GND not tied to the 5V supply's ground — §5b |
| Module seated but a rail reads 0V or −5V | Seated a row off, or doesn't reach that rail. Measure every rail before wiring — §5b |
| `fatal error: driver/gpio.h: No such file or directory` | MINIMAL_BUILD only compiles declared components — add `esp_driver_gpio esp_timer` to `PRIV_REQUIRES` (§5's firmware intro). The error names the missing component |
| SHK never changes | Divider mis-wired; multimeter the tap: ~3V off-hook. Or PD pin left high |
| Rings weakly / not at all | 5V rail sagging — add bulk capacitance; check RM/FR wires; some phones' ringers have a switch (ringer OFF slider!) |
| Ring never stops on pickup | Your ring loop isn't checking the hook — see Milestone 2's `goto answered` |
| Dial tone distorted/quiet | Codec volume vs SLIC level; adjust ES8388 output gain first, resistor divider second |
| Hum/buzz in audio | Grounds not common; audio wires running parallel to ring wires — separate them |
| DTMF misses digits | Module starved of signal — check its input cap wiring to VX; try 5V supply + dividers |
| Registers, no audio | `disallow=all` + `allow=ulaw` both ends; `direct_media=no`; RTP debug on |
| Audio one way | NAT/direct media again, or one coupling cap backwards/missing |
| WiFi drops mid-call | Power save: `esp_wifi_set_ps(WIFI_PS_NONE);` |

## 12. References

- RetroPhone (ESP32 + this exact SLIC, brilliant wiring notes): https://github.com/ktownsend-personal/RetroPhone
- ESP32-SIP-Voice (the SIP stack you'll build on, MIT): https://github.com/GeorgeBregman/ESP32-SIP-Voice
- KS0835F breakout + docs: https://github.com/GadgetReboot/KS0835F_Phone_SLIC
- ESP-IDF docs: https://docs.espressif.com/projects/esp-idf/
- Asterisk PJSIP config: https://docs.asterisk.org/
- Hobbyist phone networks for inspiration/federation: https://phreaknet.org/ · https://npstn.us

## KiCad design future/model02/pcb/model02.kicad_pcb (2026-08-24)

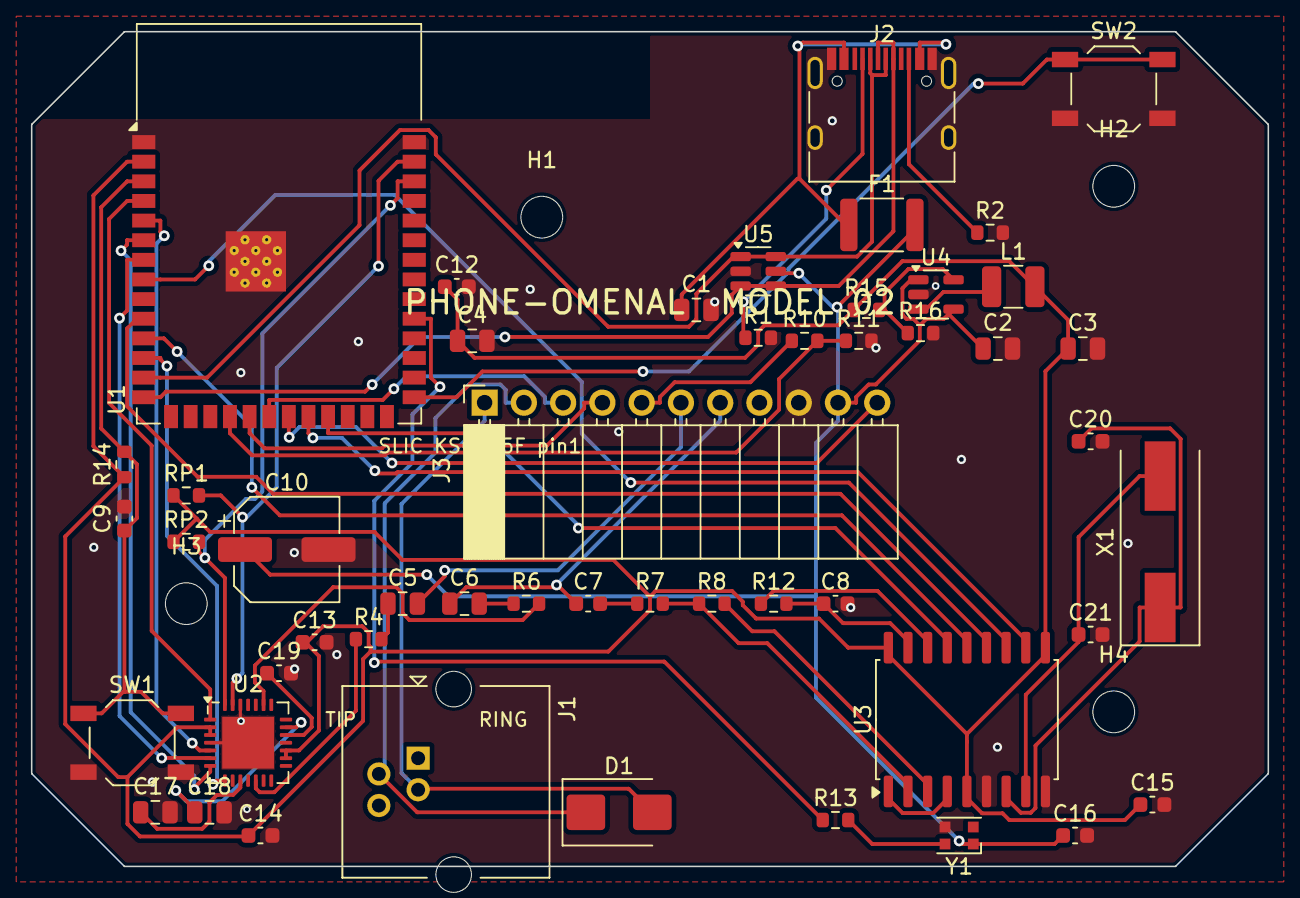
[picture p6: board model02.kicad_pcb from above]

Board: 2 copper layers, 80.0 x 54.0 mm, 54 parts (0 on the bottom side), 50 nets.

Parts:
C1, C2, C3, C4: 22uF; C_0805_2012Metric
C5, C6: 4.7uF; C_0805_2012Metric
C7, C8, C12, C13, C14, C15, C16, C19: 100nF; C_0603_1608Metric
C9: 1uF; C_0603_1608Metric
C10: 100uF; CP_Elec_6.3x5.8
C17, C18: 10uF; C_0805_2012Metric
C20, C21: 18pF; C_0603_1608Metric
D1: SMBJ100CA; D_SMB
F1: 1A polyfuse; Fuse_1812_4532Metric
H1, H2, H3, H4: MountingHole_2.7mm_M2.5
J1: RJ11-6P4C; RJ14_Connfly_DS1133-S4_Horizontal
J2: USB-C 16pin; USB_C_Receptacle_HRO_TYPE-C-31-M-12
J3: KS0835F socket; PinSocket_1x11_P2.54mm_Horizontal
L1: 2.2uH; L_1210_3225Metric
R1, R2: 5.1k; R_0603_1608Metric
R4: 100R; R_0603_1608Metric
R6, R10, R14: 10k; R_0603_1608Metric
R7, R8, R15: 100k; R_0603_1608Metric
R11: 15k; R_0603_1608Metric
R12: 300k; R_0603_1608Metric
R13: 330R; R_0603_1608Metric
R16: 22k; R_0603_1608Metric
RP1, RP2: 4.7k; R_0603_1608Metric
SW1: EN; SW_SPST_TL3342
SW2: BOOT; SW_SPST_TL3342
U1: ESP32-S3-WROOM-1-N8R2; ESP32-S3-WROOM-1
U2: ES8388; QFN-28-1EP_5x5mm_P0.5mm_EP3.35x3.35mm
U3: HT9170D; SOIC-18W_7.5x11.6mm_P1.27mm
U4: SY8089AAAC; SOT-23-5
U5: USBLC6-2SC6; SOT-23-6
X1: 3.579545MHz; Crystal_SMD_HC49-SD
Y1: WS2812B-2020; LED_WS2812B-2020_PLCC4_2.0x2.0mm

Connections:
+3V3: C3.1, C4.1, C12.1, C13.1, C14.1, C15.1, L1.2, R14.1, R15.1, RP1.1, RP2.1, U1.2, U2.2, U2.3, U2.16, U2.17, U3.5, U3.10, U3.18
+5V: C2.1, C10.1, C16.1, F1.2, J3.10, U4.1, U4.4, U5.5, Y1.1
AUD_LOUT1: R4.1, U2.12
AUD_LOUT_C: C5.1, R4.2
AUD_RIN1: R6.2, U2.23
BOOT: SW2.1, U1.27
BUCK_FB: R15.2, R16.1, U4.5
BUCK_LX: L1.1, U4.3
CC1: J2.A5, R1.1
CC2: J2.B5, R2.1
DTMF_C: C7.2, R7.1
DTMF_DV: U1.23, U3.15
DTMF_EST: R12.1, U3.16
DTMF_GS: R8.2, U3.3
DTMF_IN: R7.2, R8.1, U3.2
DTMF_Q1: U1.22, U3.11
DTMF_Q2: U1.8, U3.12
DTMF_Q3: U1.10, U3.13
DTMF_Q4: U1.11, U3.14
DTMF_STGT: C8.1, R12.2, U3.17
DTMF_VREF: U3.1, U3.4
EN: C9.1, R14.2, SW1.1, U1.3
ES_ADCVREF: C19.1, U2.19
ES_VMID: C18.1, U2.20
ES_VREF: C17.1, U2.10
GND: C1.2, C2.2, C3.2, C4.2, C8.2, C9.2, C10.2, C12.2, C13.2, C14.2, C15.2, C16.2, C17.2, C18.2, C19.2, C20.2, C21.2, J2.A1, J2.A12, J2.B1, J2.B12, J2.S1, J3.9, R1.2, R2.2, R11.2, R16.2, SW1.2, SW2.2, U1.1, U1.40, U1.41, U2.4, U2.18, U2.26, U2.29, U3.6, U3.9, U4.2, U5.2, Y1.3
I2C_SCL: RP2.2, U1.38, U2.28
I2C_SDA: RP1.2, U1.39, U2.27
I2S_BCLK: U1.5, U2.5
I2S_DIN: U1.12, U2.8
I2S_DOUT: U1.7, U2.6
I2S_LRCK: U1.6, U2.7
I2S_MCLK: U1.4, U2.1
LED_DATA: R13.2, Y1.4
LED_R: R13.1, U1.31
OSC1: C20.1, U3.7, X1.1
OSC2: C21.1, U3.8, X1.2
RING: D1.2, J1.3, J3.1
SLIC_FR: J3.3, U1.20
SLIC_PD: J3.11, U1.21
SLIC_RM: J3.4, U1.19
SLIC_SHK: R10.2, R11.1, U1.18
SLIC_SHK_5V: J3.5, R10.1
TIP: D1.1, J1.2, J3.2
USB_DM: J2.A7, J2.B7, U1.13, U5.1, U5.6
USB_DP: J2.A6, J2.B6, U1.14, U5.3, U5.4
VBUS_RAW: C1.1, F1.1, J2.A4, J2.A9, J2.B4, J2.B9
VR_IN: C5.2, J3.6
VX_C: C6.2, R6.1
VX_OUT: C6.1, C7.1, J3.7

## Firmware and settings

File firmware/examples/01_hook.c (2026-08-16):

// Milestone 1: hook detection with debounce.
// Wiring: SLIC SHK -> 10k -> (tap -> GPIO19) -> 15k -> GND; SLIC PD -> GPIO23.
#include <stdio.h>
#include "freertos/FreeRTOS.h"
#include "freertos/task.h"
#include "driver/gpio.h"
#include "esp_timer.h"

#define PIN_SHK  19
#define PIN_PD   23
#define DEBOUNCE_US 15000

static bool hook_stable = false;   // true = off hook

bool off_hook(void) { return hook_stable; }

void app_main(void) {
    gpio_config_t in = { .pin_bit_mask = 1ULL << PIN_SHK, .mode = GPIO_MODE_INPUT };
    gpio_config(&in);
    gpio_config_t out = { .pin_bit_mask = 1ULL << PIN_PD, .mode = GPIO_MODE_OUTPUT };
    gpio_config(&out);
    gpio_set_level(PIN_PD, 0);                    // SLIC awake

    bool last_raw = false;
    int64_t change_us = 0;
    while (true) {
        bool raw = gpio_get_level(PIN_SHK);
        if (raw != last_raw) { change_us = esp_timer_get_time(); last_raw = raw; }
        if (raw != hook_stable && esp_timer_get_time() - change_us > DEBOUNCE_US) {
            hook_stable = raw;
            printf(hook_stable ? "OFF HOOK\n" : "ON HOOK\n");
        }
        vTaskDelay(pdMS_TO_TICKS(2));
    }
}

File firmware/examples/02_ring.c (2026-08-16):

// Milestone 2: ring the bell. US cadence 2s on / 4s off, 20Hz.
// Wiring adds: SLIC RM -> GPIO22, SLIC F/R -> GPIO21.
// Depends on off_hook() from 01_hook.c.
#include "freertos/FreeRTOS.h"
#include "freertos/task.h"
#include "driver/gpio.h"

#define PIN_RM 22
#define PIN_FR 21

extern bool off_hook(void);

void ring_task(void *arg) {
    gpio_config_t out = { .pin_bit_mask = (1ULL<<PIN_RM) | (1ULL<<PIN_FR),
                          .mode = GPIO_MODE_OUTPUT };
    gpio_config(&out);
    while (true) {
        gpio_set_level(PIN_RM, 1);
        for (int i = 0; i < 80; i++) {            // 80 x 25ms = 2s of 20Hz
            gpio_set_level(PIN_FR, i & 1);
            vTaskDelay(pdMS_TO_TICKS(25));
            if (off_hook()) goto answered;
        }
        gpio_set_level(PIN_RM, 0);
        for (int i = 0; i < 400; i++) {           // 4s silence
            vTaskDelay(pdMS_TO_TICKS(10));
            if (off_hook()) goto answered;
        }
    }
answered:
    gpio_set_level(PIN_RM, 0);
    vTaskDelete(NULL);
}

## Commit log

2026-08-16 Open Phone Co.: an open source telephone
    Initial import: ESP32 build guide (parts, tools, six milestones),
    Asterisk switchboard configs, firmware milestone examples, parametric
    enclosures (Model 01 + 02) with STLs, and the Model 02 custom PCB
    (routed KiCad board, Gerbers, BOM, design doc, board generator scripts).
    Claude-Session: https://claude.ai/code/session_01Eo6W832gsCuN4fnhEktooj
    [model01.scad, model01_base.stl, model01_lid.stl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]
2026-08-16 Refocus on the ESP32 build; tuck the PCB away as future work
    The guide and README now center the breadboard/ESP32 project. The Model 02
    custom PCB and its enclosure move to future/model02/ with a README framing
    them as a head start for later, not the current build.
    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
    [model02-B_Courtyard.gbr, model02-B_Cu.gbl, model02-B_Fab.gbr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]
2026-08-16 Provisioning spec, box config firmware, and switchboard management app
    Spec (docs/provisioning-and-switchboard-spec.md): captive portal only when
    WiFi is failing, config page on the LAN IP + mDNS once joined, BLE web config
    always available, everything PIN-gated; numbering plan reserves 0... for
    future inter-switchboard dialing and 6XX for services.
    Firmware: 05_provision.c (WiFi fallback AP + captive DNS + PIN-gated config
    page served on both AP and LAN, admin email fetched from the switchboard API)
    and 06_ble_config.c (NimBLE GATT config service, write-only secrets).
    Server: Flask+SQLite switchboard app — admin creates users and approves
    number requests; users add devices and see per-d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
2026-08-16 Web Bluetooth setup page for the BLE config service
    Static, client-side only — the browser talks GATT directly to the box, so
    nothing hosts it: Web Bluetooth needs a secure context (https/localhost/
    file://), which the plain-HTTP switchboard can't provide. Lives next to the
    firmware whose UUIDs it must match; open from disk in Chrome/Edge.
    Claude-Session: https://claude.ai/code/session_015DGGZYr3FdyTxFbPVv1uDT
2026-08-24 Finish openphone -> phone-omenal rebrand in Docker and hardware files
    Rename the Docker containers, set the compose project name to
    phone-omenal (it previously defaulted to the directory name "server"),
    and update the remaining OPEN PHONE CO. branding in the enclosure
    models, PCB silkscreen, and docs.
    Claude-Session: https://claude.ai/code/session_01WUTRuri7Jc7HTyBfYXcJfk
    [model01.scad, model02.kicad_pcb, model02.scad]
2026-08-24 Add a macOS Docker path and detect dead SIP registrations
    Docker Desktop has no host networking, so `network_mode: host` left the
    switchboard unreachable at :8080 and every call silent — Asterisk advertised
    its container IP (172.17.x.x) in SDP, which no phone on the LAN can route to.
    Add docker-compose.mac.yml: bridge networking with published ports, with the
    switchboard joining Asterisk's network namespace so its AMI client still finds
    Asterisk on 127.0.0.1:5038 and manager.conf stays loopback-only. NAT settings
    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
2026-08-30 Fill in the gaps in the hello-world walkthrough
    Three steps that assumed knowledge a first-timer doesn't have:
    - "Plug in the AudioKit" — the board has two micro-USB sockets. Only the UART
    one is wired to the CP2102; the other is power-only, so the board lights up
    and no serial device ever appears. Note that UART carries 5V too, and that
    the second socket is useful at Milestone 2 when ring current exceeds what a
    laptop port wants to give.
    - "A serial port should appear" — didn't say where. It's a device file:
    ls /dev/cu.*, before and after. Explains cu.* vs tty.* (the tty node blocks
    on carrier detect and hangs esptool), and gives the system_profiler check
    that separates "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
2026-08-30 Target ESP-IDF v6.0.2 and document framework selection
    Move the guide off "pick the latest v5.x" onto v6.0.2, the current stable
    release, and match the firmware README. Note that the installer keeps versions
    side by side and that Select Current ESP-IDF Version switches between them, so
    a component that hasn't caught up with v6 isn't a dead end.
    Document "no framework selected to load examples", which stops the New Project
    wizard when the extension doesn't know which install to read examples from:
    reload the window, run Select Current ESP-IDF Version, check the framework
    dropdown. Extension v2.x keeps this in one setting, idf.currentSetup, rather
    than the idf.espIdfPath / idf.toolsPath pair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
2026-08-30 Make Milestone 1 followable without prior breadboard experience
    Every gap here came out of actually wiring it. The old §5 was a nine-line
    diagram that assumed breadboard fluency and named a pin that doesn't exist.
    The correction that matters: the AudioKit does not break out 5V on its pin
    headers. Both power pins are 3V3, so "AudioKit 5V ──► red rail" was
    unbuildable. §5b now covers powering the SLIC from a breadboard power module,
    which inputs to use and why, what the voltage jumpers actually select (the rail,
    not the input), and the polarity check that catches a module seated one row off
    before it destroys the SLIC. The shopping list gains the module.
    Also added: breadboard fundam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
2026-08-30 Drop the fake-phone section from Milestone 1
    Testing hook detection with a resistor across tip and ring worked, but it
    added a parts caveat and a failure mode of its own to a milestone that is
    already the first hardware step. The phone is on the shopping list; assume it.
2026-08-30 Design the firmware sections around paste-into-hello-world
    Each milestone now reuses the §4 hello-world project: select all, paste the
    milestone's code, rebuild, flash — one project, one file, and the diff between
    milestones is the code the reader just studied. Snippets carry their real
    includes and name their canonical file in firmware/examples/.
    The edit that makes it build: the v6 hello_world template sets MINIMAL_BUILD,
    so driver/gpio.h fails to resolve until esp_driver_gpio and esp_timer are added
    to main's PRIV_REQUIRES. Verified against a real v6.0.2 build — 01_hook.c
    fails without the edit and builds clean with it. The intro also explains SRCS,
    since "how does the build know wh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

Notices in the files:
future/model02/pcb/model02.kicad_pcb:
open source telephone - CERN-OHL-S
